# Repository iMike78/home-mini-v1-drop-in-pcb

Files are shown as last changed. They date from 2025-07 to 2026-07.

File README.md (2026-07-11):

# MiciMike drop-in PCB replacement for Google Home Mini (Gen 1)

[MiciMike Home Mini](https://github.com/iMike78/home-mini-v1-drop-in-pcb) is a drop-in PCB replacement for the original [Google Home Mini](https://en.wikipedia.org/wiki/Google_Nest_(smart_speakers)) with the Micro-USB power connector. It replaces the original electronics with open-source hardware based on an ESP32-S3 and an XMOS xCORE audio processor, and is intended to run ESPHome-based open voice assistant firmware.

The project follows the Home Assistant Voice Preview Edition architecture as closely as the Google Home Mini enclosure allows, while adapting the layout, connectors, controls, microphones, LEDs, and audio path to the original speaker shell.

## Current Status

- Schematic completed
- Component placement completed
- Routing completed
- Ground pour, shielding, and EMI strategy completed
- First prototype batch tested
- Validation batch received and under test
- ESPHome factory provisioning validated with BLE Improv and Home Assistant discovery

## Update: v0.9.5 Touch Controller Migration and Test Points

### Touch Controller Change

The ESP32-S3 built-in touch peripheral has been replaced with an external **MPR121 capacitive touch controller** on the I2C bus at address `0x5A`. This avoids an unresolved ESP-IDF / hardware issue (`IDFGH-16448`) where the touch sensor FSM could lock up and leave all channels stuck at their maximum raw value.

What changed:

- **Hardware:** MPR121 added on the clean `+3V3` rail. Touch pads connect through `ELEC0` to `ELEC2`; IRQ is on `GPIO2`. Unused electrodes are tied together to GND through a single 1 Mohm resistor.
- **Firmware:** the ESPHome `esp32_touch` component was removed and replaced with an `mpr121` hub plus three binary sensors for `volume_down`, `center_button`, and `volume_up`.
- **Freed pins:** ESP32-S3 `GPIO3` and `GPIO4` are no longer used for capacitive touch.

The center touch button is also used as the BLE Improv authorizer in the factory firmware, matching the Home Assistant Voice PE provisioning flow.

### New Solderable Test Points

The board exposes large, easy-to-solder test points for users who do not have the original Google Home Mini daughterboard and FPC connector, or who want to integrate the PCB into a custom enclosure.

- **+5V and GND power input pads:** allow direct power injection without using the original FPC connector.
- **Mute switch pad:** exposes the hardware mute input, which has an on-board pull-up. Pull this pad to GND to power the microphones; otherwise the board remains muted and the microphone path is disabled.

## ESPHome Firmware

The ESPHome configuration lives in [esphome/](./esphome/):

- [micimike-factory.yml](./esphome/micimike-factory.yml) is the manufacturing / first-install firmware. It mirrors the Home Assistant Voice PE factory flow: BLE Improv provisioning, center-button authorization, Home Assistant discovery, and the full voice firmware configuration included underneath.
- [micimike-voice.yml](./esphome/micimike-voice.yml) is the full voice assistant firmware configuration used by the factory build and by normal ESPHome installs.

Typical factory flashing:

```bash
esphome run esphome/micimike-factory.yml
```

After flashing, Home Assistant should discover the device via BLE Improv, ask for Wi-Fi credentials, request center-button authorization, and then add the ESPHome device. The fallback Wi-Fi AP is present, but no captive portal or web server is intentionally enabled.

## Crowdfunding

The crowdfunding campaign is live on Crowd Supply in its pre-order phase. You can subscribe there to show interest and receive email updates:

https://www.crowdsupply.com/micimike-rev-devices/micimike-home-mini-drop-in-pcb

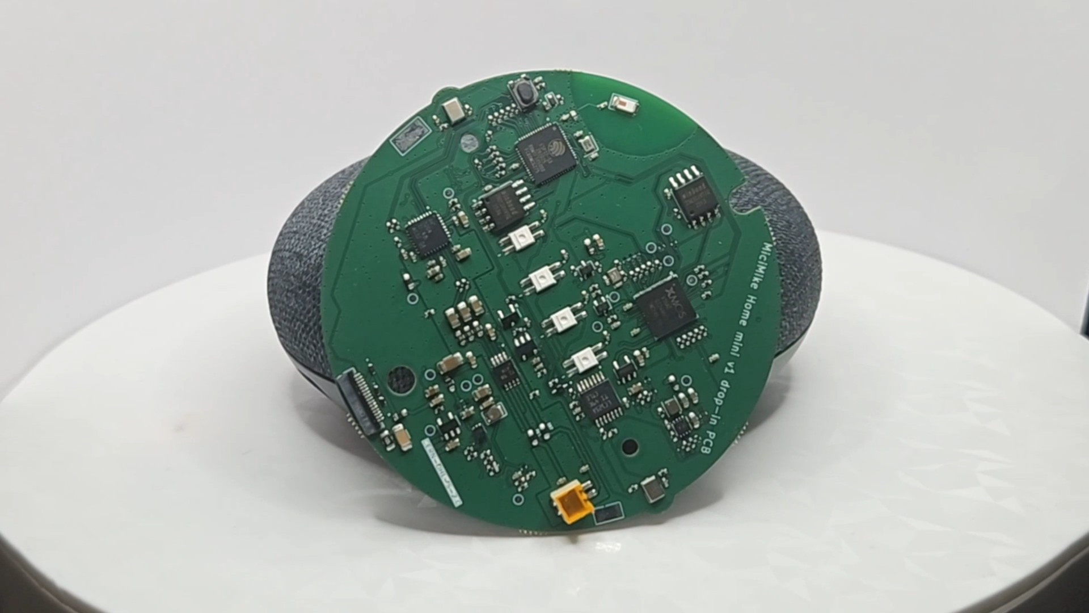
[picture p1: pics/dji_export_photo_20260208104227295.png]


If you are looking for a similar drop-in PCB replacement for the Google Nest Mini, see the sister project:

https://github.com/iMike78/nest-mini-drop-in-pcb

## Project Scope

This repository and its sister project are open-source hardware projects inspired in part by [Onju Voice](https://github.com/justLV/onju-voice), but designed around the open voice assistant hardware direction established by the Open Home Foundation and Home Assistant Voice Preview Edition.

The primary target audience is people who want to repurpose Google Home Mini and Google Nest Mini speakers into open-source Home Assistant voice assistant hardware and/or media player speaker output for [Music Assistant](https://www.music-assistant.io). The hardware may also be useful for other ESP32-based firmware projects.

The design integrates:

- ESP32-S3 for Wi-Fi, BLE, ESPHome, and onboard wake-word detection
- XMOS xCORE XU316 for advanced audio processing
- Local audio cleanup support for noise suppression, acoustic echo cancellation, interference cancellation, and automatic gain control

Functionally, the goal is to stay as compatible as practical with the [Home Assistant Voice Preview Edition](https://www.home-assistant.io/blog/2024/12/19/voice-preview-edition-the-era-of-open-voice/) reference design. The main differences come from the tight mechanical constraints of the Google Home Mini enclosure and original components.

This repository is not intended to become a separate upstream for new ESPHome or XMOS voice features. Feature development should generally happen upstream:

- https://github.com/esphome/home-assistant-voice-pe
- https://github.com/esphome/esphome
- https://github.com/esphome/voice-kit-xmos-firmware

## Collaboration and Contributions

If you would like to support the project, you can buy me a coffee via Ko-fi:

https://ko-fi.com/imike78

Contributions are especially welcome from people with board-level electrical design, KiCad layout, PCB routing, ground-pour strategy, EMI, and mixed-signal audio layout experience. Please open an issue, join an existing discussion, or start a new discussion in this repository.

Background discussion on the Home Assistant community forum:

https://community.home-assistant.io/t/any-news-on-alternative-to-onju-voice-pcb-repacement-design-for-google-nest-home-mini-speakers-with-added-xmos-chip-to-match-of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

## Tools Used

- KiCad 9
- SnapEDA / LCSC for footprint sourcing

## Known Hardware Specifications

- 4-layer PCB
- ESP32-S3R8 bare chip with 16MB flash
- XMOS XU316-1024-QF60B-C24 xCORE DSP audio processor with 4MB flash
- Dual I2S buses for simultaneous audio input and output
- AIC3204 DAC and TPA6211 power amplifier for speaker output
- 2x T3902 MEMS microphones with 68mm spacing
- 4x SK6812 RGB LEDs
- MPR121 capacitive touch controller

## References

### Home Assistant Voice Preview Edition

- https://www.home-assistant.io/blog/2024/12/19/voice-preview-edition-the-era-of-open-voice/
- https://voice-pe.home-assistant.io/resources/
- https://support.nabucasa.com/hc/en-us/categories/24451727188125-Home-Assistant-Voice-Preview-Edition
- https://github.com/esphome/home-assistant-voice-pe
- https://esphome.github.io/home-assistant-voice-pe/

### XMOS xCORE DSP

- https://www.xmos.com/download/XU316-1024-QF60B-xcore.ai-Datasheet(3).pdf
- https://www.xmos.com/software-tools/
- https://www.xmos.com/develop/xcore-voice
- https://www.xmos.com/usb-multichannel-audio/
- https://www.xmos.com/xcore-ai

### XMOS Firmware

- https://github.com/esphome/voice-kit-xmos-firmware
- https://github.com/esphome/xmos_fwk_rtos
- https://github.com/esphome/xmos_fwk_io

## License

This project is licensed under the [CERN Open Hardware License Version 2 - Strongly Reciprocal (CERN-OHL-S v2)](./LICENCE).

Any modified version of this hardware must also be distributed under the same license.

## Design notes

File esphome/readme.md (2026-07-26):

# MiciMike ESPHome Firmware

This directory contains the ESPHome firmware configuration for MiciMike.

## Files

```text
esphome/
|-- micimike-factory.yml  # Factory / first-install firmware
|-- micimike-voice.yml    # Full voice assistant firmware
```

## Factory Firmware

`micimike-factory.yml` follows the Home Assistant Voice Preview Edition factory pattern. It is not a tiny bootstrap-only image; it includes the full MiciMike voice assistant configuration and adds the first-install provisioning layer on top.

The factory overlay provides:

- BLE Improv provisioning
- Serial Improv provisioning
- Home Assistant discovery
- Center-button authorization for BLE Improv
- BLE disable after Wi-Fi connection, after a short delay so Improv can report success
- HTTP update entity backed by the GitHub release manifest
- Optional beta firmware update source switch

The fallback Wi-Fi AP is present, but `captive_portal:` and `web_server:` are intentionally not enabled. ESPHome may warn about this during validation; that is expected for this provisioning model.

## BLE Improv Flow

1. Flash the factory firmware over USB.
2. Home Assistant discovers the device via BLE Improv.
3. Home Assistant asks for Wi-Fi credentials.
4. Home Assistant asks for center-button authorization.
5. The device connects to Wi-Fi and is added as an ESPHome device.

The center button is implemented through the MPR121 capacitive touch controller on channel 1.

## Home Assistant Takeover

Factory firmware advertises the full `micimike-voice.yml` configuration through `dashboard_import` and enables full configuration import. After Home Assistant takes control, the generated ESPHome configuration should be the complete voice firmware config, not a short package wrapper pointing back to `micimike-factory.yml`.

The imported configuration must not add a station Wi-Fi `ssid` or `password`. Wi-Fi credentials entered through BLE Improv are stored on the device and should be preserved across OTA updates. Adding `wifi_ssid` / `wifi_password` secrets to the adopted config will override the Improv-provisioned network on the next ESPHome build.

If a device was adopted before this behavior was fixed, delete or manually repair the old short wrapper config in ESPHome before updating it again.

## Flashing

From the repository root:

```bash
esphome run esphome/micimike-factory.yml
```

To flash a known serial port:

```bash
esphome run esphome/micimike-factory.yml --device COM8
```

## Release Manifest

GitHub releases should provide `manifest.json`, `manifest-beta.json`, and the firmware binary referenced by the manifest.

Example:

```json
{
  "name": "MiciMike Voice Assistant",
  "version": "v0.9.8.2",
  "builds": [
    {
      "chipFamily": "ESP32-S3",
      "improv": false,
      "parts": [
        {
          "path": "micimike-voice.bin",
          "offset": 0
        }
      ]
    }
  ]
}
```

Expected release assets:

```text
manifest.json
manifest-beta.json
micimike-voice.bin
```

## Notes

- The factory firmware mirrors the Home Assistant Voice PE provisioning behavior as closely as possible.
- The factory firmware already contains the full voice assistant configuration through `micimike-voice.yml`.
- Home Assistant takeover should import the full `micimike-voice.yml` config and preserve BLE Improv Wi-Fi credentials.
- The HTTP update entity can check the GitHub release manifest, but installing an update still depends on the ESPHome/Home Assistant update flow.
- Future firmware updates are not forced automatically; users can update through Home Assistant or ESPHome when a release is available.

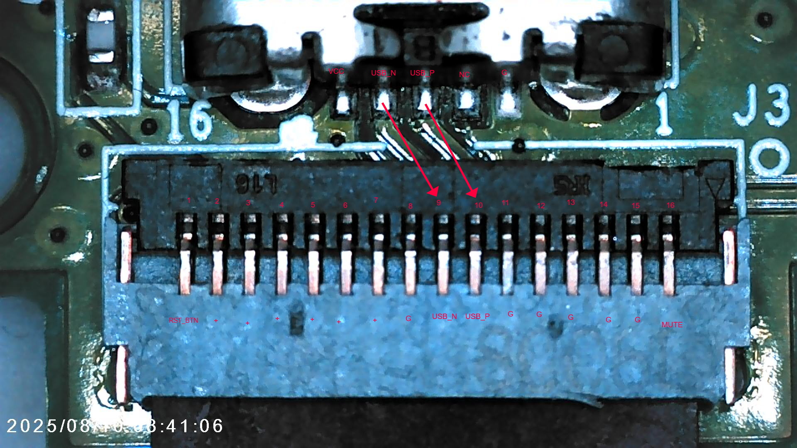
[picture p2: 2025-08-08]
pics/FPC_pinout.jpg

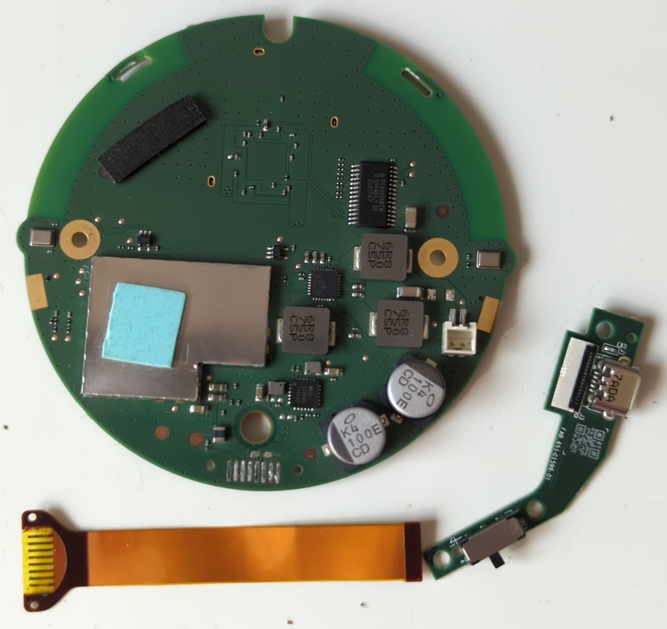
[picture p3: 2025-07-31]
pics/original_PCB.jpg

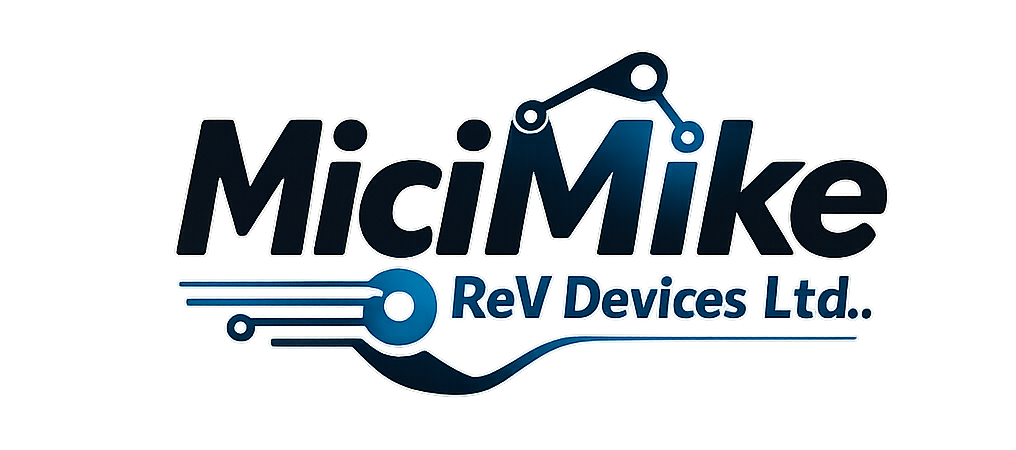
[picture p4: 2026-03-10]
pics/MiciMike.png

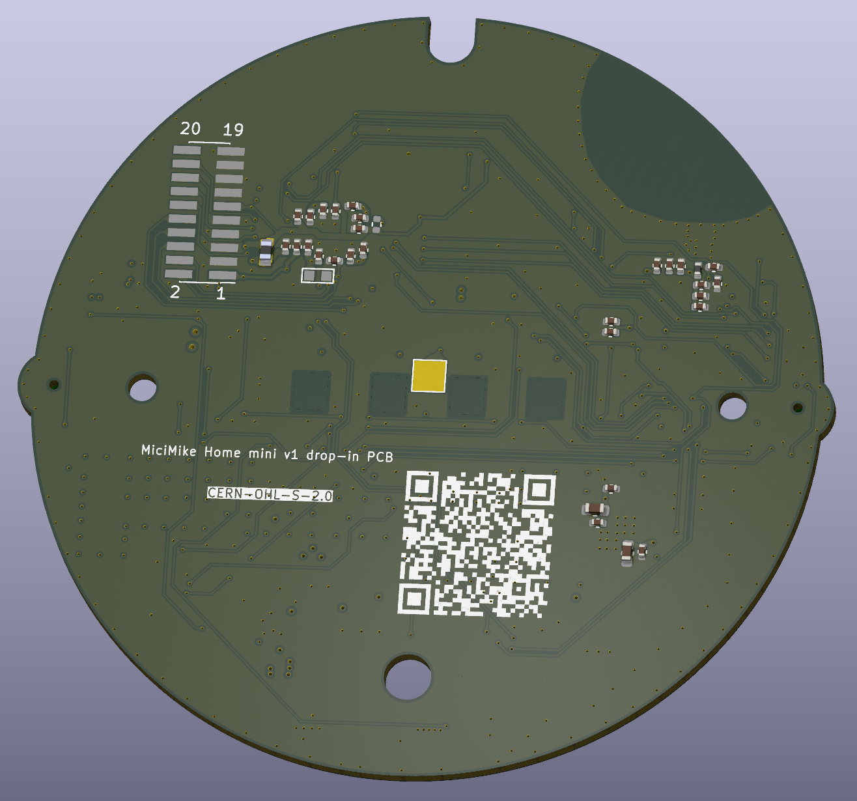
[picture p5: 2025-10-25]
pics/3D_bottom.png

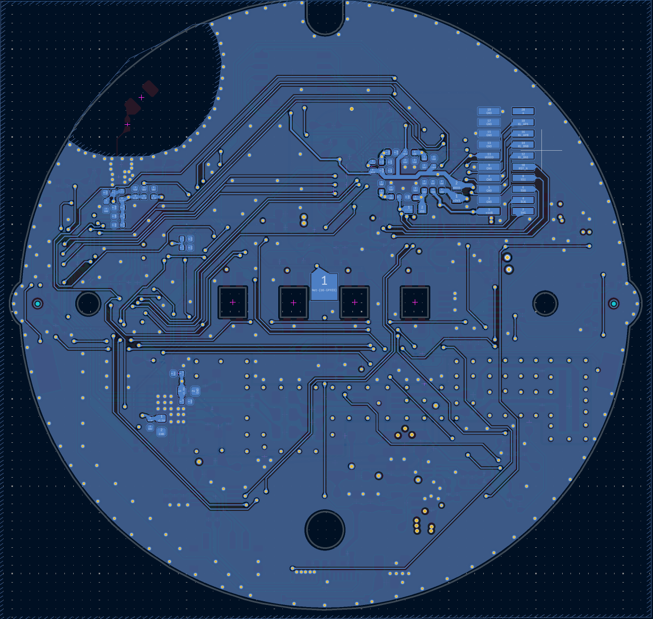
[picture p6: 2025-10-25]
pics/B_Cu.png

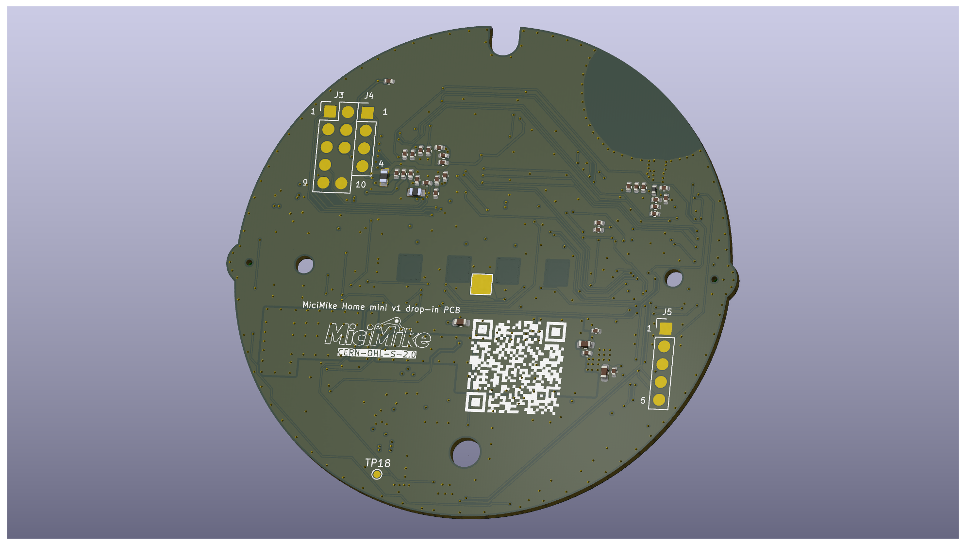
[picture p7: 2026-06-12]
pics/home-mini-DiP-Gen1-back.png

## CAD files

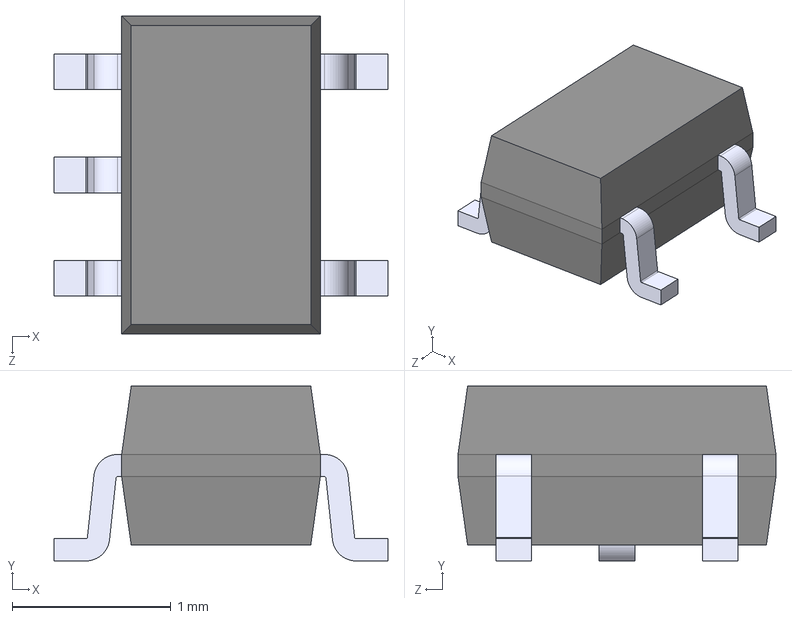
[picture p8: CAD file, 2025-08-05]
parts/MIC5365-1.8YC5-TR.step
2.10 x 1.10 x 2.00 mm

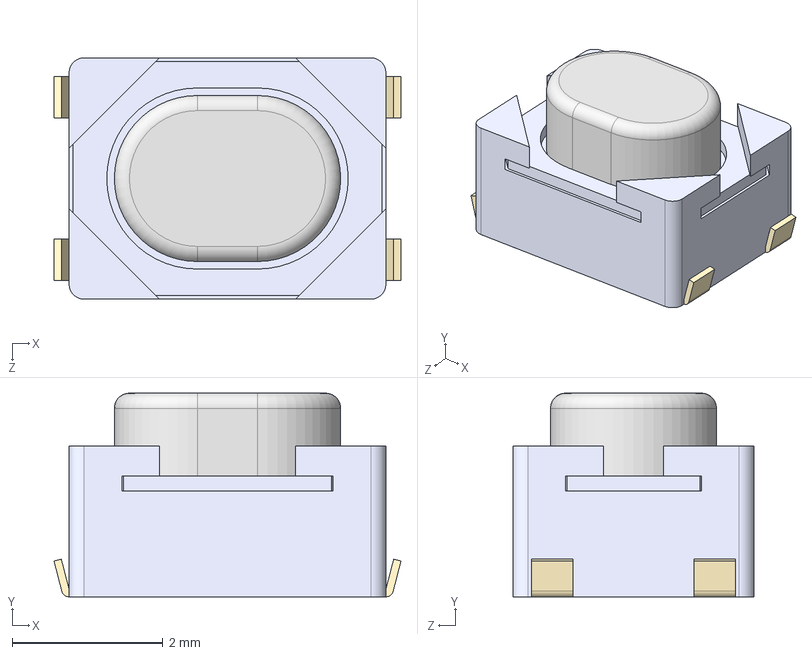
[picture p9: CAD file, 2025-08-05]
parts/PTS810SJS250SMTRLFS--3DModel-STEP-56544.STEP
4.60 x 2.70 x 3.20 mm

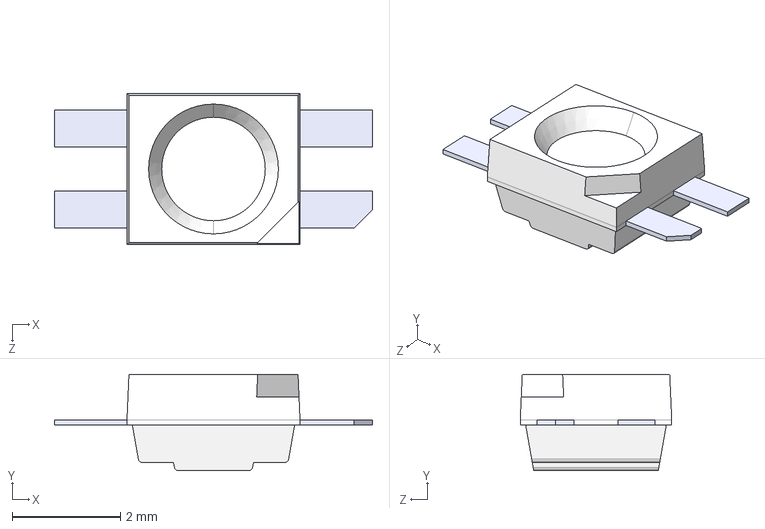
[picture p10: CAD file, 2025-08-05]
parts/SK6812-E.step
5.88 x 1.78 x 2.80 mm

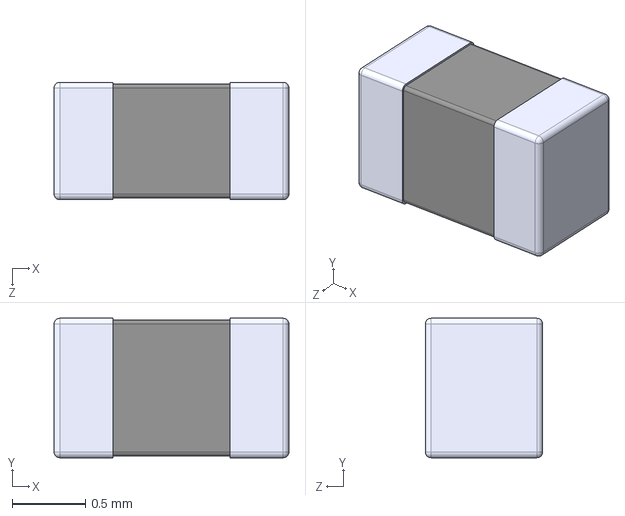
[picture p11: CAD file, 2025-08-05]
parts/BLM18PG121SN1D.step
1.60 x 0.95 x 0.8 mm

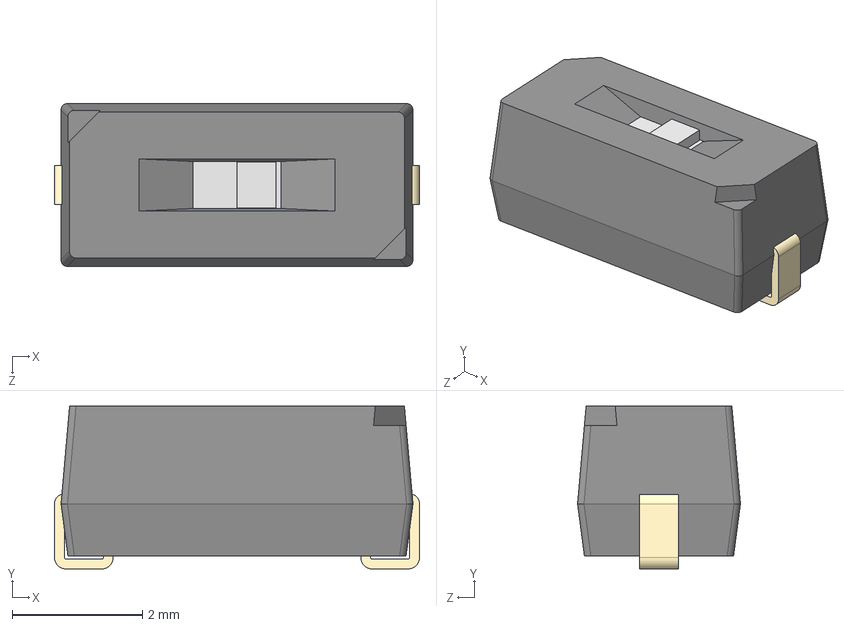
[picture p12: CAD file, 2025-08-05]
parts/CHS-01TA.step
5.60 x 2.50 x 2.50 mm
CHS-01 body
pin^CHS-01xx
switch^CHS-01xx

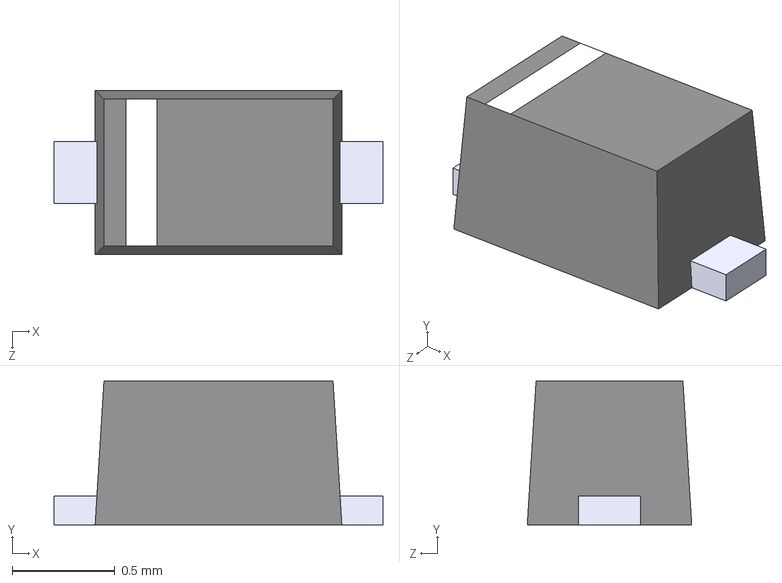
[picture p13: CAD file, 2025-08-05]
parts/RB521S30T1G.step
1.60 x 0.7 x 0.8 mm

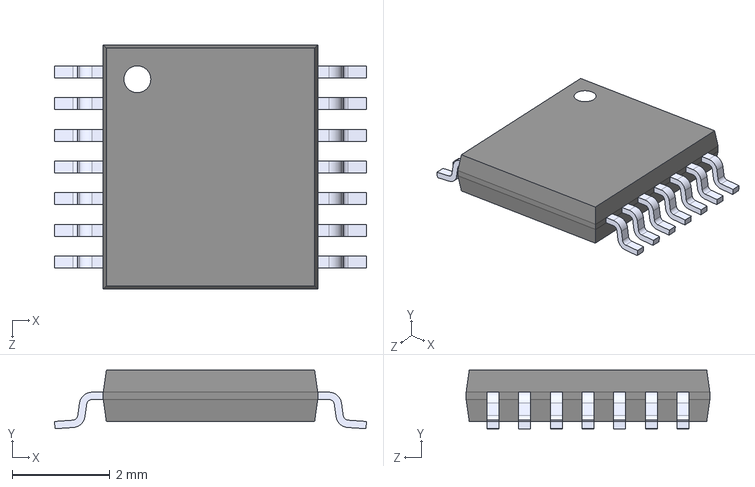
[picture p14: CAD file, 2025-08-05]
parts/SN74LVC125APWR.step
6.40 x 1.20 x 5.00 mm

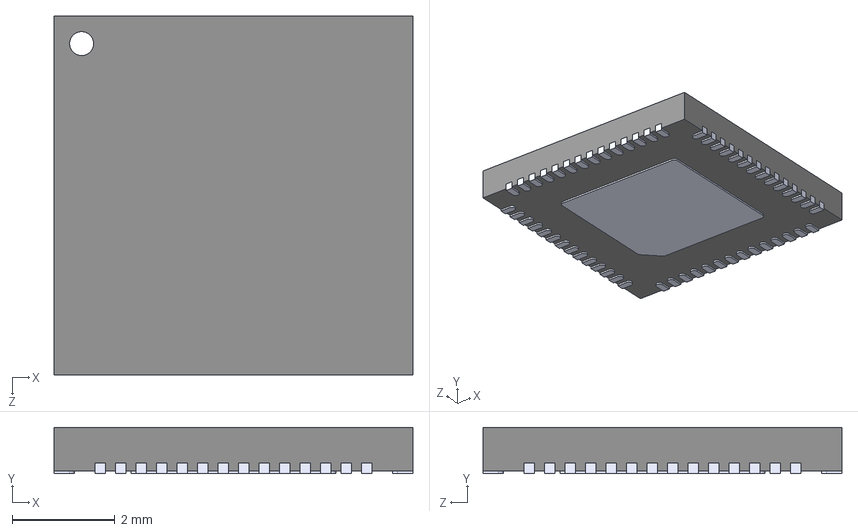
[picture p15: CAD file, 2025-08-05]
parts/ESP32-S3R8.step
7.00 x 0.9 x 7.00 mm

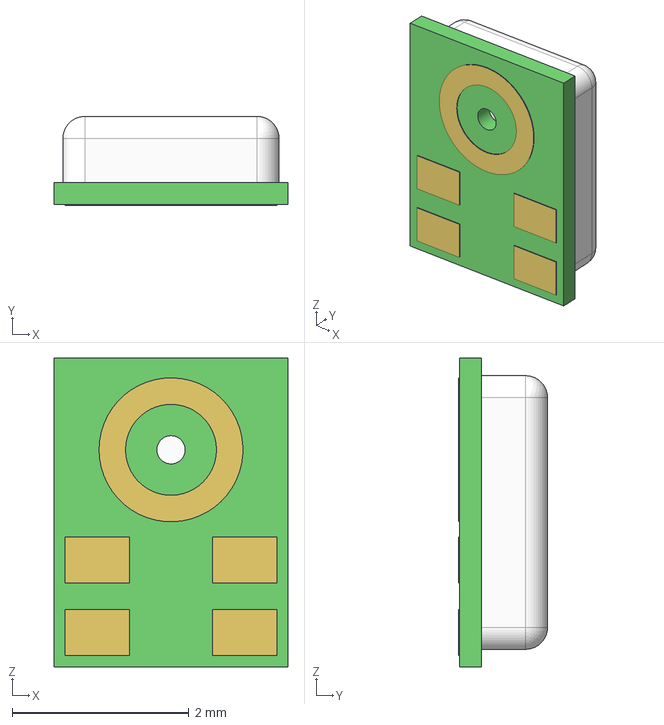
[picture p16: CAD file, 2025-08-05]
parts/DMM-3526-B-R.step
2.65 x 1.01 x 3.50 mm

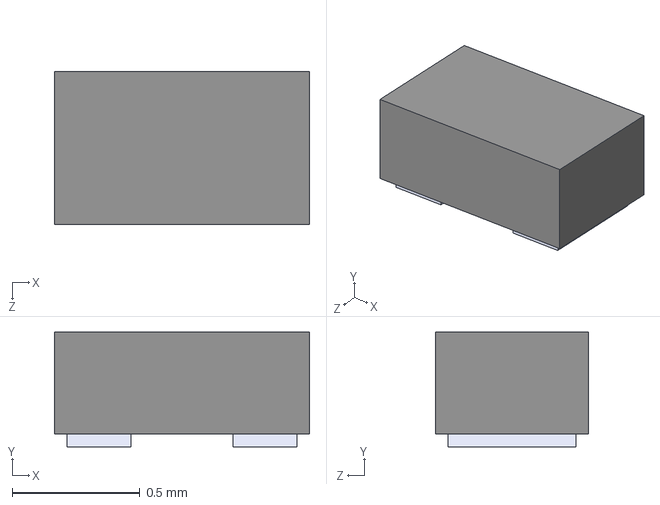
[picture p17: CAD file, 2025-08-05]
parts/TPD1E10B06DPYR.step
1.00 x 0.45 x 0.6 mm

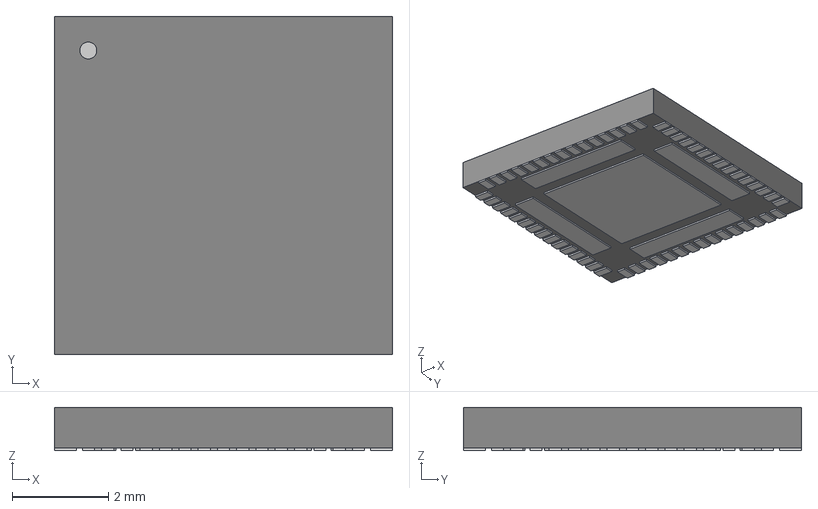
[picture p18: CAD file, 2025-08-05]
parts/QFN_F60B-C24_XMO.step
7.01 x 7.01 x 0.892 mm

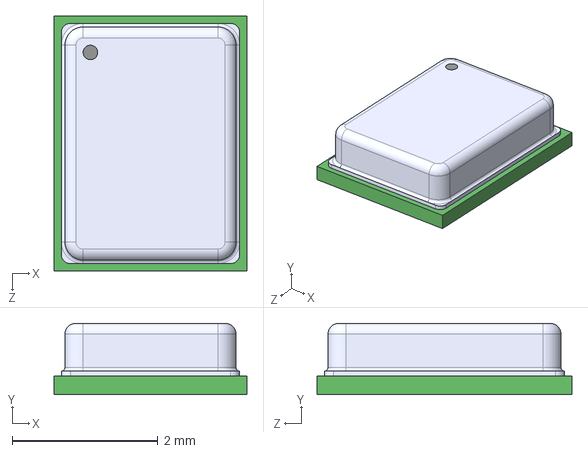
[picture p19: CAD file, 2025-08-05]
parts/T3902.step
2.65 x 0.98 x 3.50 mm

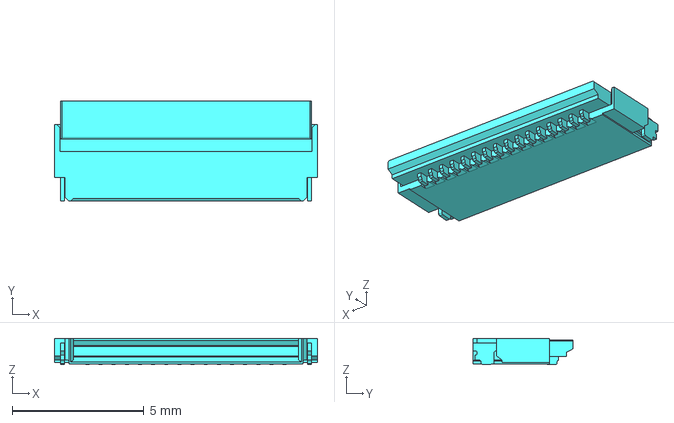
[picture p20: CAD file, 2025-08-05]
parts/FH34SRJ-16S-0.5SH-99---3DModel-STEP-1.STEP
10.0 x 3.80 x 1.00 mm

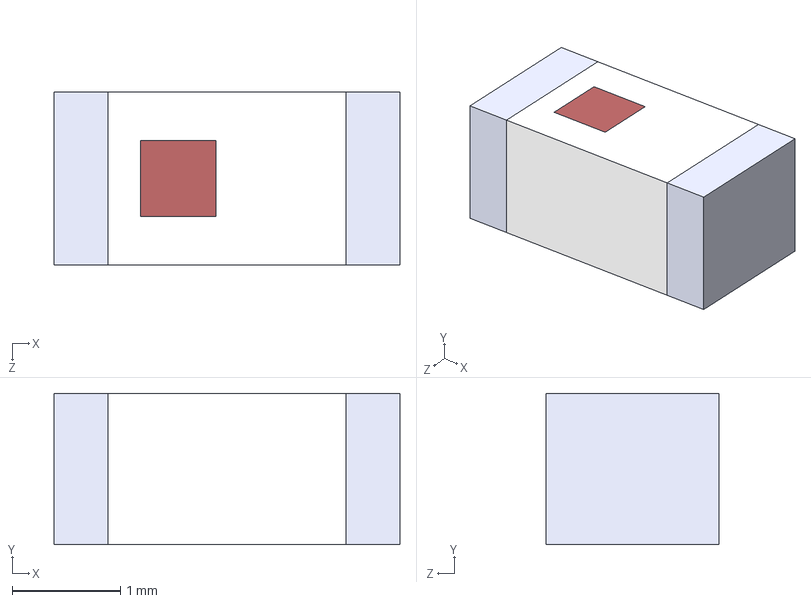
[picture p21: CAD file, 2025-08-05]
parts/2450AT18A100E.step
3.20 x 1.40 x 1.60 mm

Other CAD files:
parts/1775443-2.stp
parts/MAX98357AETE_T.step
parts/TLV73333PDBVR.step
parts/TPS563201DDCT.step

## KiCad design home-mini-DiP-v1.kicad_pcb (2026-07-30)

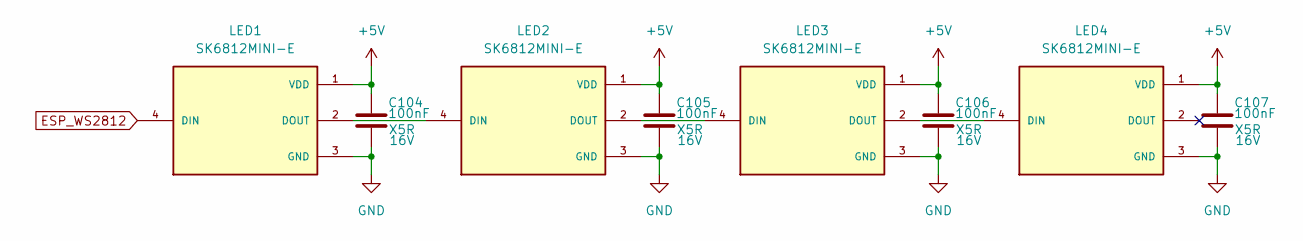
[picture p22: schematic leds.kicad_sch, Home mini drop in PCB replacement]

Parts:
C104, C105, C106, C107: 100nF; C_0402_1005Metric; Voltage 16V; Manufacturer Part CL05B104KO5NNNC; LCSC Part # C1525
LED1, LED2, LED3, LED4: SK6812MINI-E; Manufacturer Part SK6812MINI-E; LCSC Part # C5149201

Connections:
+5V: C104.1, C105.1, C106.1, C107.1, LED1.1 (VDD), LED2.1 (VDD), LED3.1 (VDD), LED4.1 (VDD); also elsewhere on the board
ESP_WS2812: LED1.4 (DIN); also elsewhere on the board
GND: C104.2, C105.2, C106.2, C107.2, LED1.3 (GND), LED2.3 (GND), LED3.3 (GND), LED4.3 (GND); also elsewhere on the board
unnamed: LED1.2 (DOUT), LED2.4 (DIN)
unnamed: LED2.2 (DOUT), LED3.4 (DIN)
unnamed: LED3.2 (DOUT), LED4.4 (DIN)

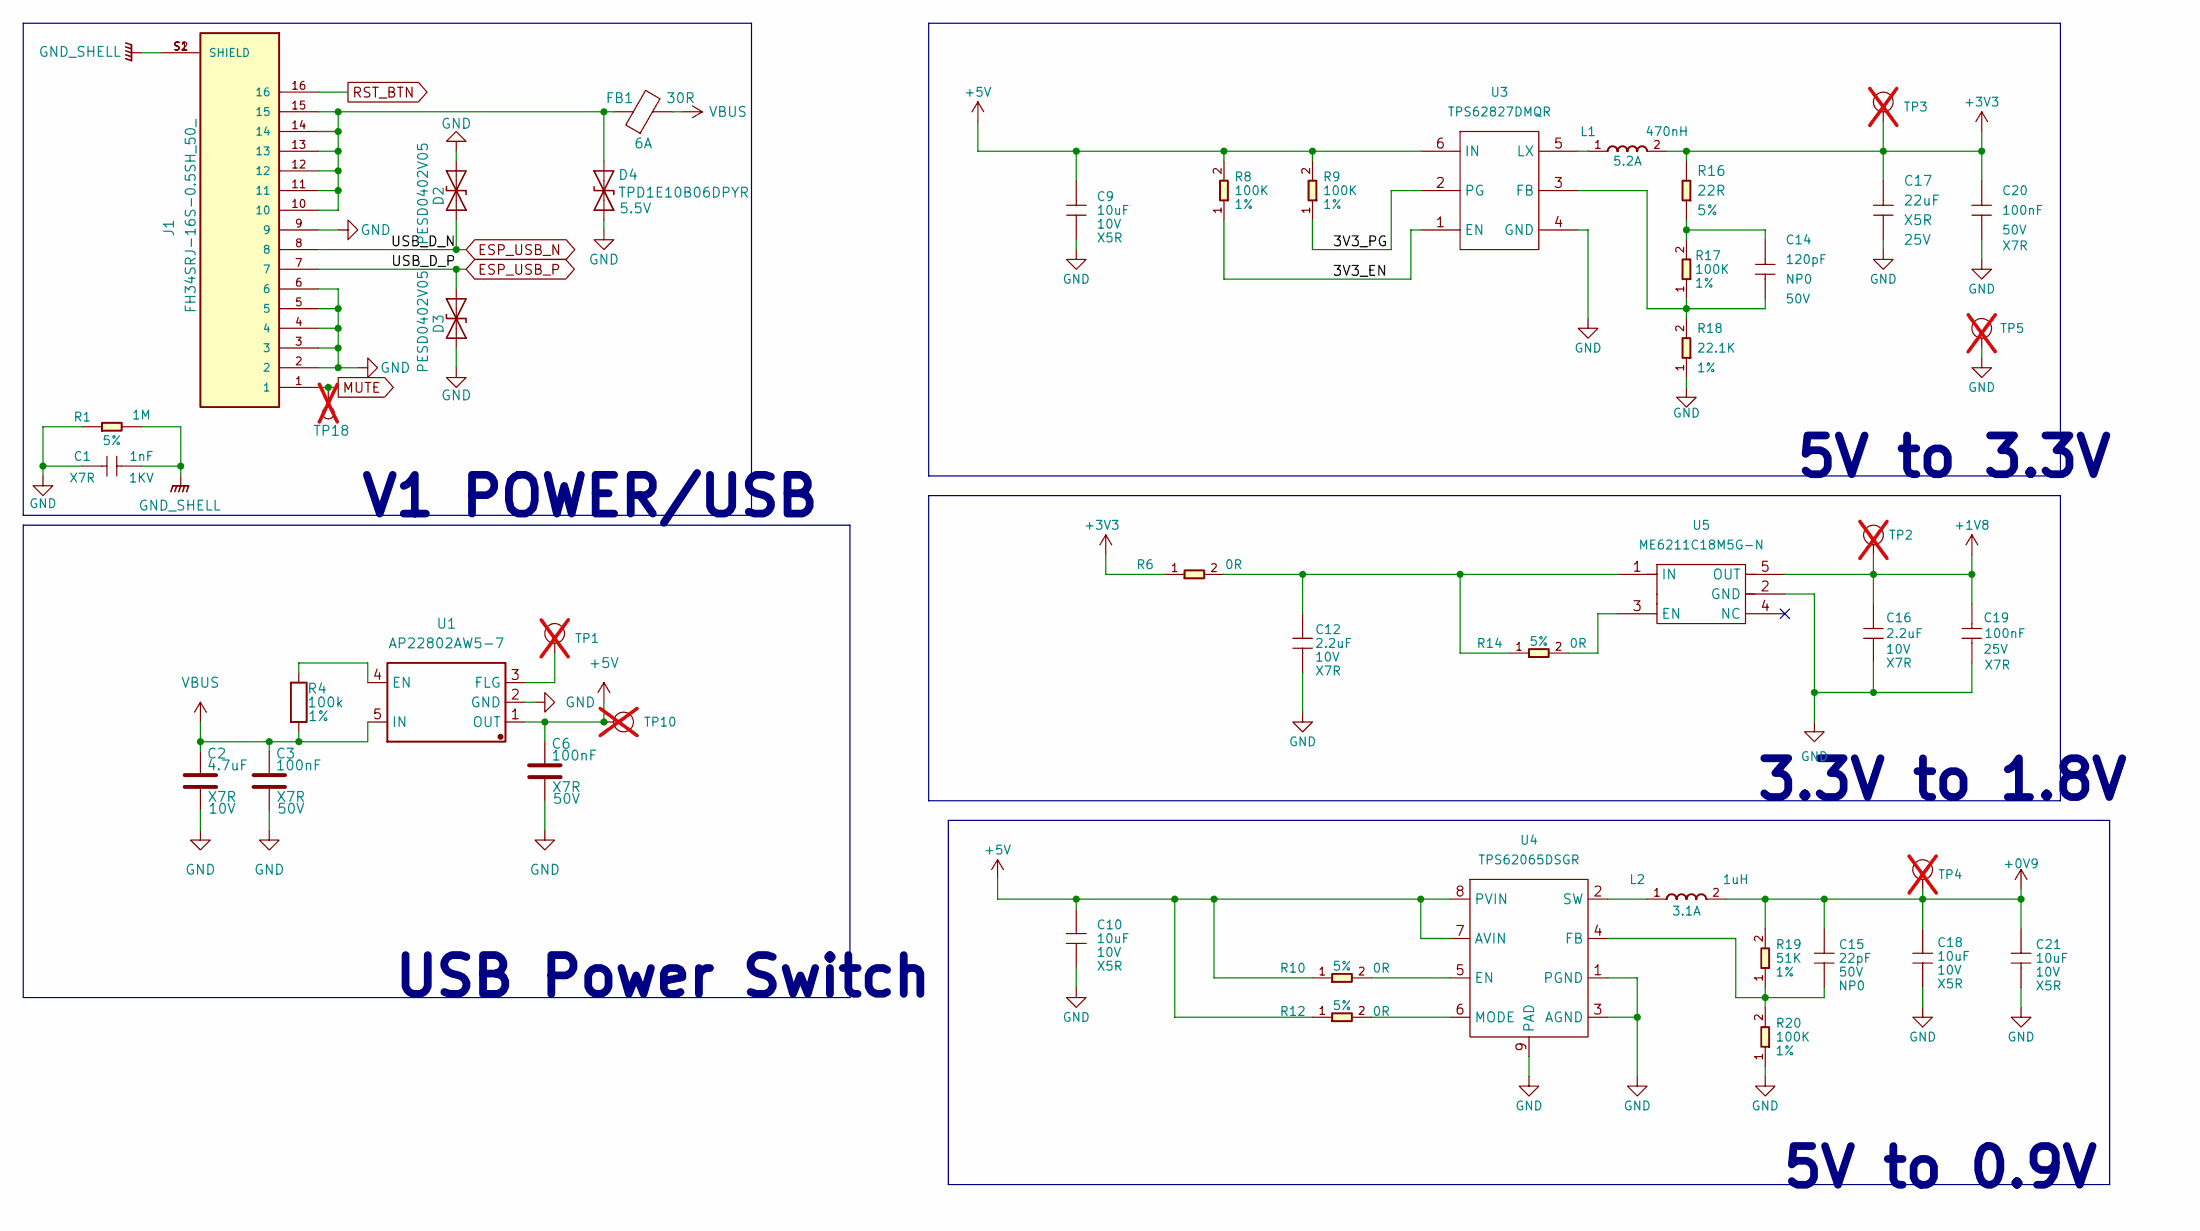
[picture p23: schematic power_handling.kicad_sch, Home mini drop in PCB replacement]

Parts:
C1: 1nF; C_1206_3216Metric; Voltage Rating 1KV; Voltage 2kV; MPN 1206B102K202NT; LCSC Part # C9196
C2: 4.7uF; C_0603_1608Metric; Voltage 10V; Manufacturer Part GRM188Z71A475KE15D; LCSC Part # C913474
C3, C6: 100nF; C_0603_1608Metric; Voltage 50V; Manufacturer Part CC0603KRX7R9BB104; LCSC Part # C14663
C9, C10, C18, C21: 10uF; C_0603_1608Metric; Voltage Rating 10V; Voltage 10V; MPN CL10A106KP8NNNC; LCSC Part # C19702
C12, C16: 2.2uF; C_0603_1608Metric; Voltage Rating 10V; Voltage 16V; MPN 0603B225K160NT; LCSC Part # C43922
C14: 120pF; C_0402_1005Metric; Voltage Rating 50V; Voltage 50V; MPN 0402CG121J500NT; LCSC Part # C40059
C15: 22pF; C_0402_1005Metric; Voltage Rating 50V; Voltage 50V; MPN 0402CG220J500NT; LCSC Part # C1555
C17: 22uF; C_0805_2012Metric; Voltage Rating 25V; Voltage 25V; MPN CL21A226MAQNNNE; LCSC Part # C45783
C19: 100nF; C_0402_1005Metric; Voltage Rating 25V; Voltage 16V; MPN CL05B104KO5NNNC; LCSC Part # C1525
C20: 100nF; C_0603_1608Metric; Voltage Rating 50V; Voltage 50V; MPN CC0603KRX7R9BB104; LCSC Part # C14663
D2, D3: PESD0402V05; D_0402_1005Metric; Manufacturer Part PESD0402V05; LCSC Part # C19626254
D4: TPD1E10B06DPYR; TPD1E05U06DPYR; Voltage 5.5V; Manufacturer Part TPD1E10B06DPYR; LCSC Part # C48260
FB1: 30R; BLM18PG300SN1D; Manufacturer Part BLM18PG300SN1D; LCSC Part # C17305
J1: FH34SRJ-16S-0.5SH_50_; HRS_FH34SRJ-16S-0.5SH_50_; Manufacturer Part FH34SRJ-16S-0.5SH(50); LCSC Part # C324725
L1: 470nH; L0806; Rating 5.2A; MPN WPN201610MR47MT; LCSC Part # C97014
L2: 1uH; L_Murata_DFE201610P; Rating 3.1A; MPN WPN201610U1R0MTY01; LCSC Part # C395545
R1: 1M; R_0805_2012Metric; Power Rating 5%; MPN RC0805JR-071ML; LCSC Part # C107699
R4: 100k; R_0402_1005Metric; Tolerance 1%; Manufacturer Part 0402WGJ0104TCE; LCSC Part # C25530
R6, R10, R12, R14: 0R; R_0402_1005Metric; Tolerance 5%; MPN 0402WGF0000TCE; LCSC Part # C17168
R8, R9, R17: 100K; R_0402_1005Metric; Power Rating 1%; MPN 0402WGJ0104TCE; LCSC Part # C25530
R16: 22R; R_0402_1005Metric; Power Rating 5%; MPN 0402WGF220JTCE; LCSC Part # C25092
R18: 22.1K; R_0402_1005Metric; Power Rating 1%; MPN 0402WGF2212TCE; LCSC Part # C43473
R19: 51K; R_0402_1005Metric; Tolerance 1%; MPN 0402WGF5102TCE; LCSC Part # C25794
R20: 100K; R_0402_1005Metric; Tolerance 1%; MPN 0402WGJ0104TCE; LCSC Part # C25530
TP1, TP2, TP3, TP4: TEST-POINT; TestPoint_Pad_D1.0mm; not fitted
TP5, TP10: TEST-POINT; TestPoint_Pad_D3.0mm; not fitted
TP18: MUTE; TestPoint_Pad_D1.0mm; not fitted
U1: AP22802AW5-7; SOT-23-5; Manufacturer Part AP22802AW5-7; LCSC Part # C211404
U3: TPS62827DMQR; DFN6-0.5-1.5X1.5X0.65MM; MPN TPS62827DMQR; LCSC Part # C2071448
U4: TPS62065DSGR; MPN TPS62065DSGR; LCSC Part # C398352
U5: ME6211C18M5G-N; SOT-23-5; MPN ME6211C18M5G-N; LCSC Part # C236671

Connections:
+0V9: C15.1, C18.1, C21.1, L2.2, R19.2, TP4.1 (T); also elsewhere on the board
+1V8: C16.1, C19.1, TP2.1 (T), U5.5 (OUT); also elsewhere on the board
+3V3: C17.1, C20.1, L1.2, R6.1, R16.2, TP3.1 (T); also elsewhere on the board
+5V: C6.1, C9.1, C10.1, R8.2, R9.2, R10.1, R12.1, TP10.1 (T), U1.1 (OUT), U3.6 (IN), U4.7 (AVIN), U4.8 (PVIN); also elsewhere on the board
/Power/3V3_EN: R8.1, U3.1 (EN)
/Power/3V3_PG: R9.1, U3.2 (PG)
ESP_USB_N: D2.2 (A2), J1.8; also elsewhere on the board
ESP_USB_P: D3.1 (A1), J1.7; also elsewhere on the board
GND: C1.1, C2.2, C3.2, C6.2, C9.2, C10.2, C12.2, C16.2, C17.2, C18.2, C19.2, C20.2, C21.2, D2.1 (A1), D3.2 (A2), D4.1 (A1), J1.2, J1.3, J1.4, J1.5, J1.6, J1.9, R1.1, R18.1, R20.1, TP5.1 (T), U1.2 (GND), U3.4 (GND), U4.1 (PGND), U4.3 (AGND), U4.9 (PAD), U5.2 (GND); also elsewhere on the board
GND_SHELL: C1.2, J1.S1 (SHIELD), J1.S2 (SHIELD), R1.2
MUTE: J1.1, TP18.1; also elsewhere on the board
unnamed: C14.1, R16.1, R17.2
unnamed: D4.2 (A2), FB1.1, J1.10, J1.11, J1.12, J1.13, J1.14, J1.15
unnamed: TP1.1 (T), U1.3 (FLG)
unnamed: R4.1, U1.4 (EN)
unnamed: C14.2, R17.1, R18.2, U3.3 (FB)
unnamed: L1.1, U3.5 (LX)
unnamed: R10.2, U4.5 (EN)
unnamed: C15.2, R19.1, R20.2, U4.4 (FB)
unnamed: R12.2, U4.6 (MODE)
unnamed: L2.1, U4.2 (SW)
unnamed: R14.2, U5.3 (EN)
unnamed: C12.1, R6.2, R14.1, U5.1 (IN)
RST_BTN: J1.16; also elsewhere on the board
VBUS: C2.1, C3.1, FB1.2, R4.2, U1.5 (IN); also elsewhere on the board

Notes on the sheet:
V1 POWER/USB
USB Power Switch
3.3V to 1.8V
5V to 3.3V
5V to 0.9V

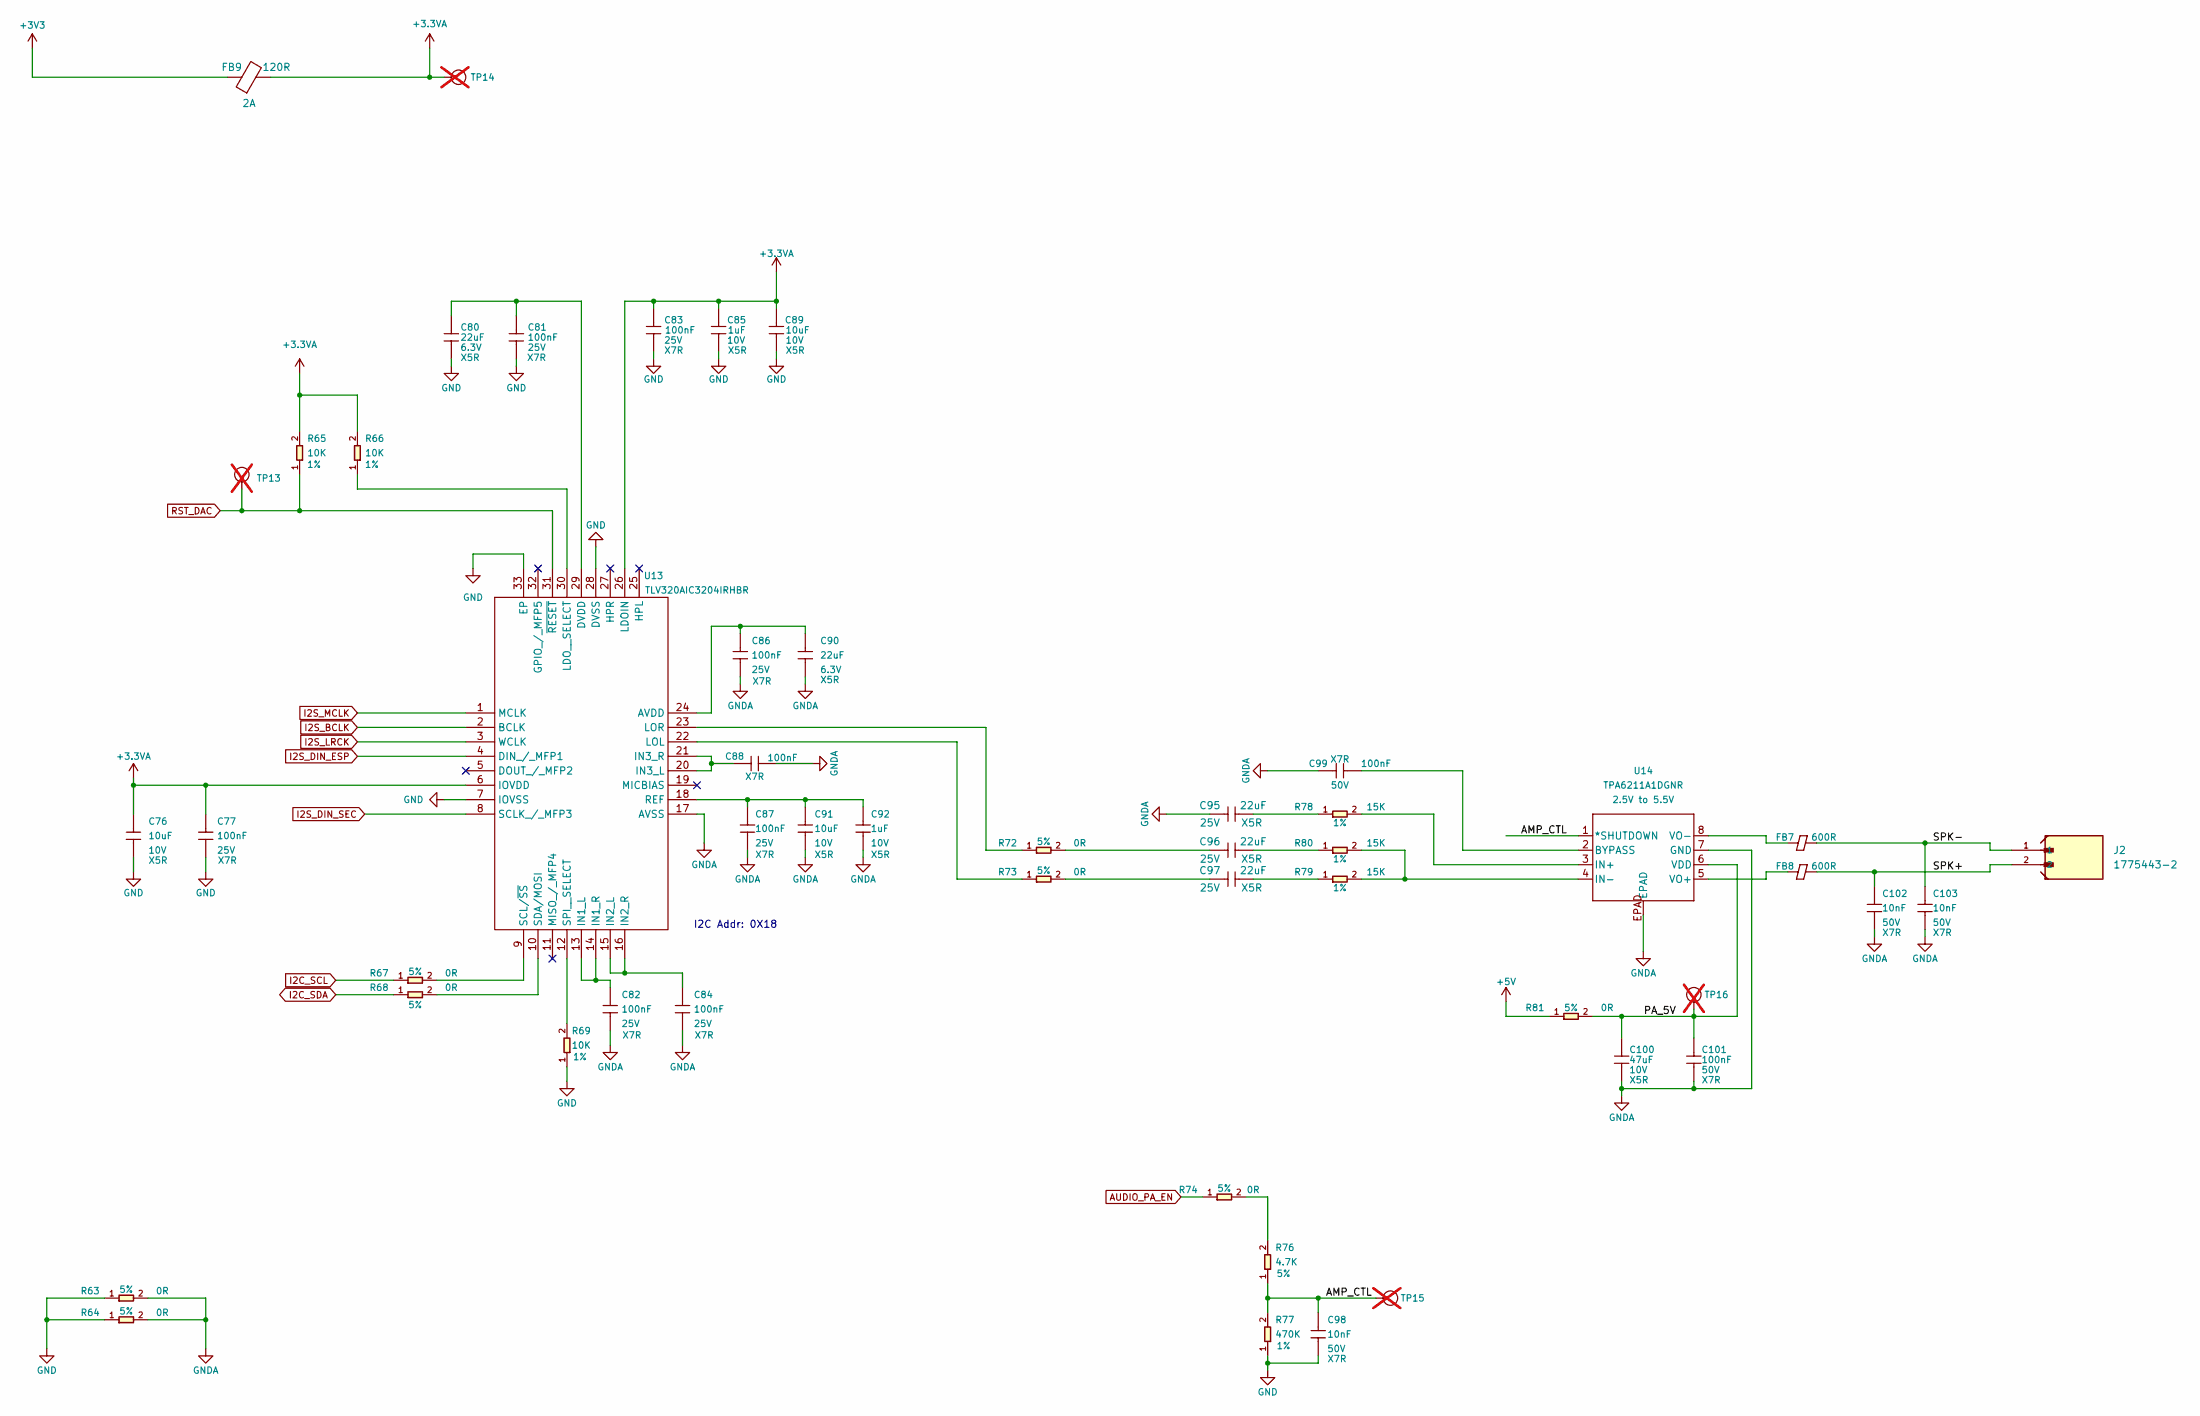
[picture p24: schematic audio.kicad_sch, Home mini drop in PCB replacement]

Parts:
C76, C89, C91: 10uF; C_0603_1608Metric; Voltage Rating 10V; Voltage 10V; MPN CL10A106KP8NNNC; LCSC Part # C19702
C77, C81, C82, C83, C84, C86, C87, C88: 100nF; C_0402_1005Metric; Voltage Rating 25V; Voltage 16V; MPN CL05B104KO5NNNC; LCSC Part # C1525
C80, C90: 22uF; C_0603_1608Metric; Voltage Rating 6.3V; Voltage 6.3V; MPN CL10A226MQ8NRNC; LCSC Part # C59461
C85, C92: 1uF; C_0402_1005Metric; Voltage Rating 10V; MPN CL05A105KA5NQNC; LCSC Part # C52923
C95, C96, C97: 22uF; C_0805_2012Metric; Voltage Rating 25V; Voltage 25V; MPN CL21A226MAQNNNE; LCSC Part # C45783
C98, C102, C103: 10nF; C_0402_1005Metric; Voltage Rating 50V; Voltage 50V; MPN CL05B103KB5NNNC; LCSC Part # C15195
C99, C101: 100nF; C_0603_1608Metric; Voltage Rating 50V; Voltage 50V; MPN CC0603KRX7R9BB104; LCSC Part # C14663
C100: 47uF; C_1206_3216Metric; Voltage Rating 10V; Voltage 10V; MPN CL31A476MPHNNNE; LCSC Part # C96123
FB7, FB8: 600R; BLM18PG121SN1D; Rating 500mA; MPN BLM18KG601SN1D; LCSC Part # C85833
FB9: 120R; BLM18PG121SN1D; Manufacturer Part BLM18PG121SN1D; LCSC Part # C14709
J2: 1775443-2; Manufacturer Part 1775443-2; LCSC Part # C5162845
R63, R64, R67, R68, R72, R73, R74: 0R; R_0402_1005Metric; Tolerance 5%; MPN 0402WGF0000TCE; LCSC Part # C17168
R65, R66, R69: 10K; R_0402_1005Metric; Tolerance 1%; MPN 0402WGF1002TCE; LCSC Part # C25744
R76: 4.7K; R_0402_1005Metric; Tolerance 5%; MPN 0402WGF4701TCE; LCSC Part # C25900
R77: 470K; R_0402_1005Metric; Tolerance 1%; Manufacturer Part 0402WGF4703TCE; LCSC Part # C25790
R78, R79, R80: 15K; R_0603_1608Metric; Tolerance 1%; Manufacturer Part 0603WAF1502T5E; LCSC Part # C22809
R81: 0R; R_0603_1608Metric; Tolerance 5%; Manufacturer Part 0603WAF0000T5E; LCSC Part # C21189
TP13, TP15: TEST-POINT; TestPoint_Pad_D1.0mm; not fitted
TP14, TP16: Test Point; TestPoint_Pad_D1.0mm; Part Type Test Point; not fitted
U13: TLV320AIC3204IRHBR; MPN TLV320AIC3204IRHBR; Mouser Part Number 595-V320AIC3204IRHBR
U14: TPA6211A1DGNR; Rating 2.5V to 5.5V; MPN TPA6211A1DGNR; LCSC Part # C7718

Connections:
+3.3VA: C76.1, C77.1, C83.1, C85.1, C89.1, FB9.2, R65.2, R66.2, TP14.1 (T), U13.6 (IOVDD), U13.26 (LDOIN)
+3V3: FB9.1; also elsewhere on the board
+5V: R81.1; also elsewhere on the board
/AUDIO/AMP_CTL: C98.1, R76.1, R77.2, TP15.1 (T), U14.1 (*SHUTDOWN)
/AUDIO/PA_5V: C100.1, C101.1, R81.2, TP16.1 (T), U14.6 (VDD)
/AUDIO/SPK+: C102.1, FB8.2, J2.2
/AUDIO/SPK-: C103.1, FB7.2, J2.1
AUDIO_PA_EN: R74.1; also elsewhere on the board
GND: C76.2, C77.2, C80.2, C81.2, C83.2, C85.2, C89.2, C98.2, R63.1, R64.1, R69.1, R77.1, U13.7 (IOVSS), U13.28 (DVSS), U13.33 (EP); also elsewhere on the board
GNDA: C82.2, C84.2, C86.2, C87.2, C88.2, C90.2, C91.2, C92.2, C95.1, C99.1, C100.2, C101.2, C102.2, C103.2, R63.2, R64.2, U13.17 (AVSS), U14.7 (GND), U14.EPAD
I2C_SCL: R67.1; also elsewhere on the board
I2C_SDA: R68.1; also elsewhere on the board
I2S_BCLK: U13.2 (BCLK); also elsewhere on the board
I2S_DIN_ESP: U13.4 (DIN_/_MFP1); also elsewhere on the board
I2S_DIN_SEC: U13.8 (SCLK_/_MFP3); also elsewhere on the board
I2S_LRCK: U13.3 (WCLK); also elsewhere on the board
I2S_MCLK: U13.1 (MCLK); also elsewhere on the board
unnamed: C95.2, R78.1
unnamed: C96.1, R72.2
unnamed: C96.2, R80.1
unnamed: C97.1, R73.2
unnamed: C97.2, R79.1
unnamed: R74.2, R76.2
unnamed: C86.1, C90.1, U13.24 (AVDD)
unnamed: C80.1, C81.1, U13.29 (DVDD)
unnamed: C82.1, U13.13 (IN1_L), U13.14 (IN1_R)
unnamed: C84.1, U13.15 (IN2_L), U13.16 (IN2_R)
unnamed: C88.1, U13.20 (IN3_L), U13.21 (IN3_R)
unnamed: R66.1, U13.30 (LDO__SELECT)
unnamed: R73.1, U13.22 (LOL)
unnamed: R72.1, U13.23 (LOR)
unnamed: C87.1, C91.1, C92.1, U13.18 (REF)
unnamed: R67.2, U13.9 (SCL/~SS)
unnamed: R68.2, U13.10 (SDA/MOSI)
unnamed: R69.2, U13.12 (SPI__SELECT)
unnamed: C99.2, U14.2 (BYPASS)
unnamed: R78.2, U14.3 (IN+)
unnamed: R79.2, R80.2, U14.4 (IN-)
unnamed: FB8.1, U14.5 (VO+)
unnamed: FB7.1, U14.8 (VO-)
RST_DAC: R65.1, TP13.1 (T), U13.31 (~RESET); also elsewhere on the board

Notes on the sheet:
I2C Addr: 0X18

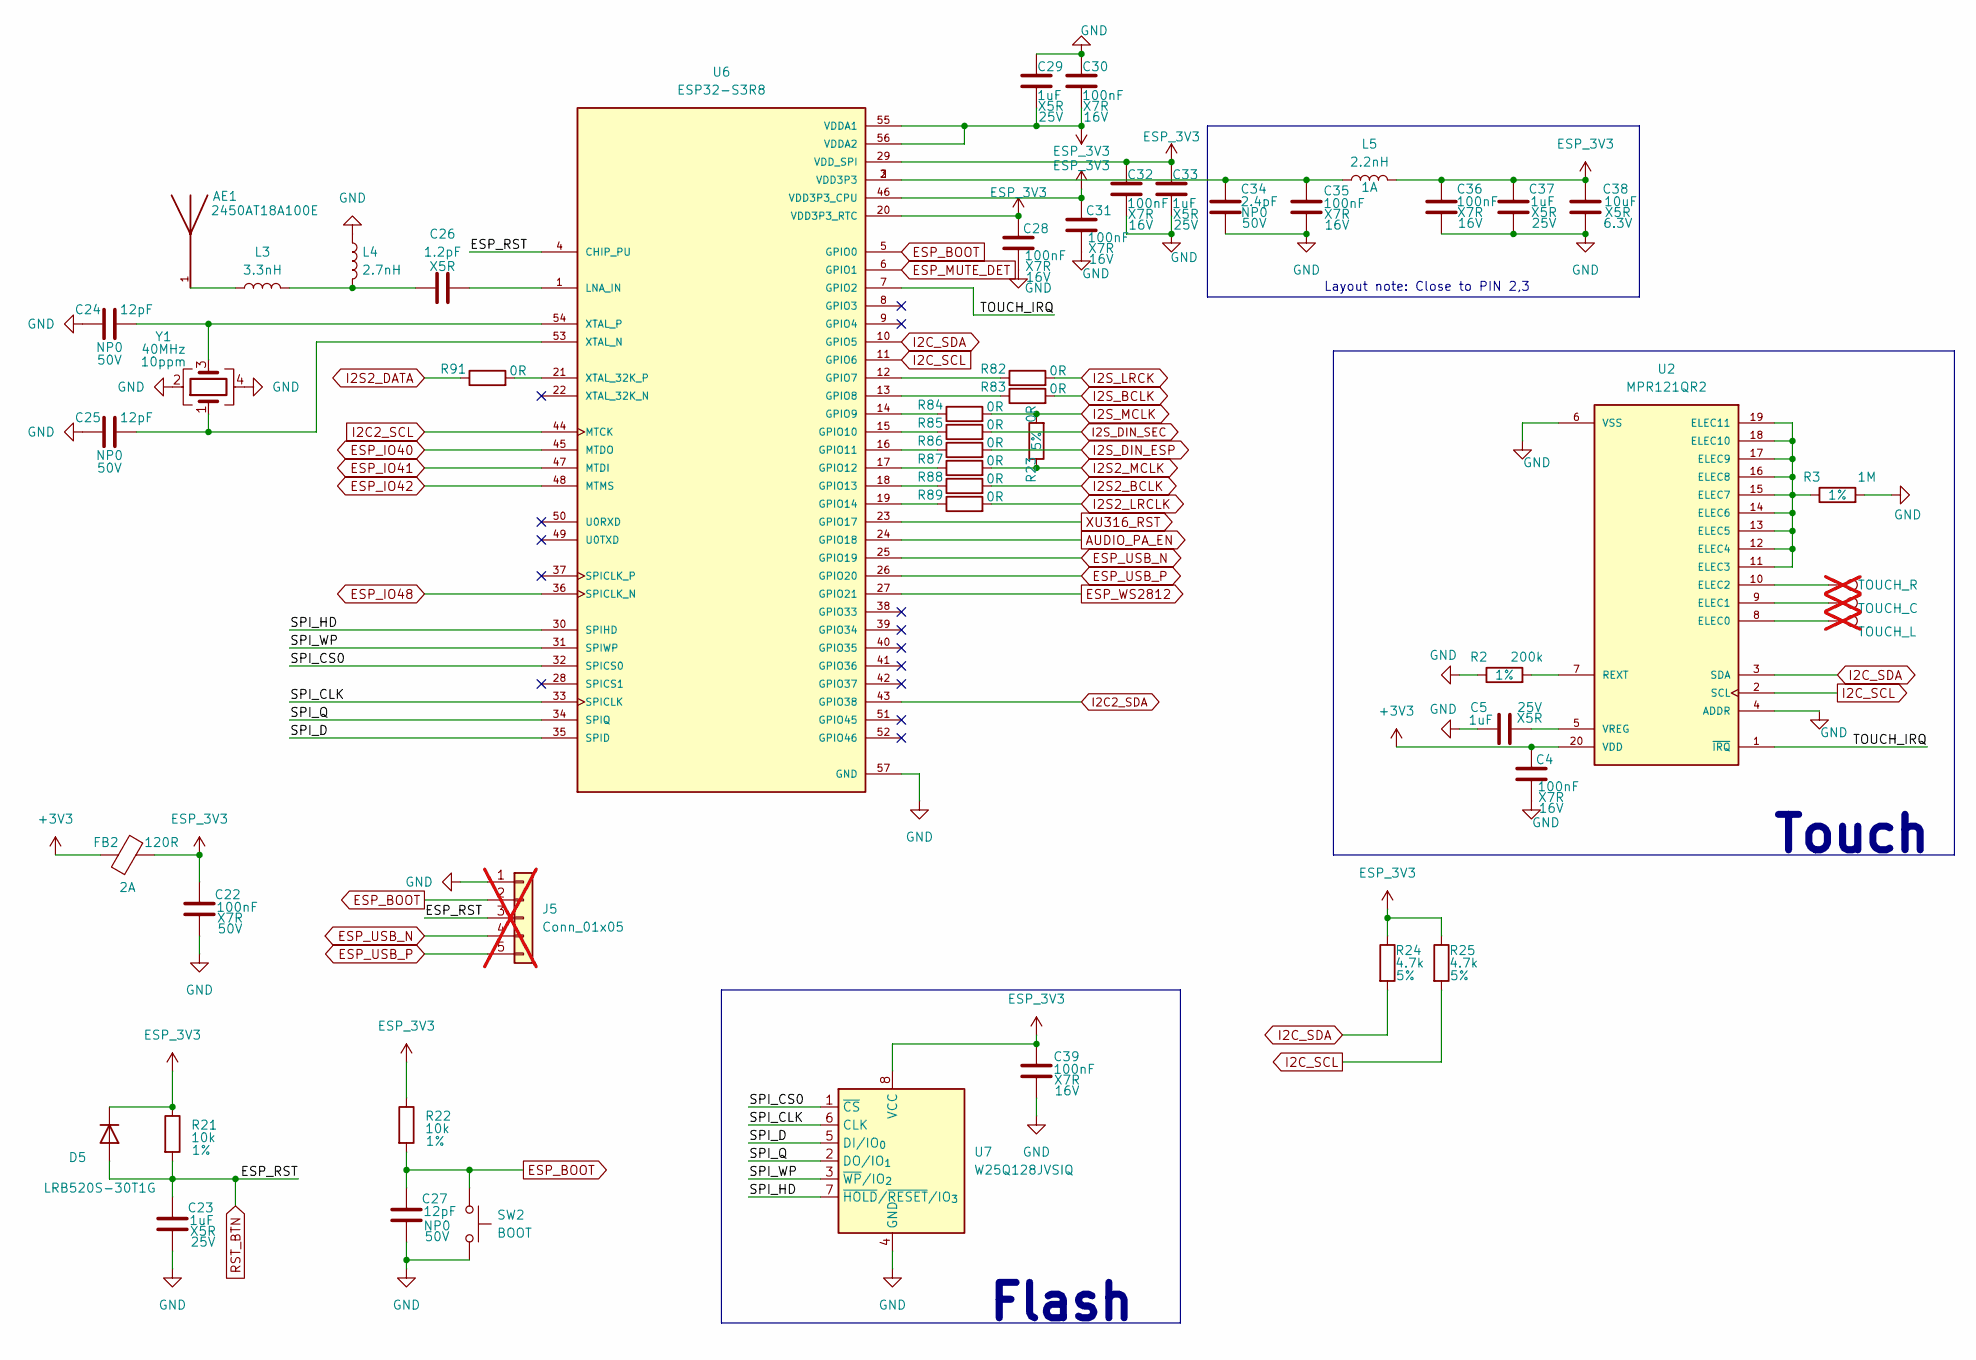
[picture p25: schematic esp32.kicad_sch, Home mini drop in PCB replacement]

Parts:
AE1: 2450AT18A100E; Johanson_2450AT18x100; Manufacturer Part 2450AT18A100E; LCSC Part # C89334
C4, C28, C30, C31, C32, C35, C36, C39: 100nF; C_0402_1005Metric; Voltage 16V; Manufacturer Part CL05B104KO5NNNC; LCSC Part # C1525
C5, C23, C29, C33, C37: 1uF; C_0402_1005Metric; Voltage 25V; Manufacturer Part CL05A105KA5NQNC; LCSC Part # C52923
C22: 100nF; C_0603_1608Metric; Voltage 50V; Manufacturer Part CC0603KRX7R9BB104; LCSC Part # C14663
C24, C25, C27: 12pF; C_0402_1005Metric; Voltage 50V; Manufacturer Part 0402CG120J500NT; LCSC Part # C1547
C26: 1.2pF; C_0402_1005Metric; Voltage 10V; Manufacturer Part CC0402BRNPO9BN1R2; LCSC Part # C327292
C34: 2.4pF; C_0402_1005Metric; Voltage 50V; Manufacturer Part 0402CG2R4C500NT; LCSC Part # C48346
C38: 10uF; C_0402_1005Metric; Voltage 6.3V; Manufacturer Part CL05A106MQ5NUNC; LCSC Part # C15525
D5: LRB520S-30T1G; D_SOD-523; Manufacturer Part LRB520S-30T1G; LCSC Part # C83680
FB2: 120R; BLM18PG121SN1D; Manufacturer Part BLM18PG121SN1D; LCSC Part # C14709
J5: Conn_01x05; PinHeader_1x05_P2.54mm_Vertical; not fitted
L3: 3.3nH; L_0402_1005Metric; Manufacturer Part SDCL1005C3N3STDF; LCSC Part # C16526
L4: 2.7nH; L_0402_1005Metric; Manufacturer Part MHQ1005P2N7BT000; LCSC Part # C434826
L5: 2.2nH; L_0402_1005Metric; Manufacturer Part LQG15HS2N2B02D; LCSC Part # C162540
R2: 200k; R_0402_1005Metric; Tolerance 1%; MPN 0402WGF2003TCE; LCSC Part # C25764
R3: 1M; R_0402_1005Metric; Tolerance 1%; MPN 0402WGJ0105TCE; LCSC Part # C26087
R21, R22: 10k; R_0402_1005Metric; Tolerance 1%; Manufacturer Part 0402WGF1002TCE; LCSC Part # C25744
R23, R82, R83, R84, R85, R86, R87, R88, R89, R91: 0R; R_0402_1005Metric; Tolerance 5%; Manufacturer Part 0402WGF0000TCE; LCSC Part # C17168
R24, R25: 4.7k; R_0402_1005Metric; Tolerance 5%; Manufacturer Part 0402WGF4701TCE; LCSC Part # C25900
SW2: BOOT; SW-SMD_4P-L4.2-W3.2-P2.15-LS4.5; Manufacturer Part PTS810SJS250SMTRLFS; LCSC Part # C221897
TP6: TOUCH_L; TestPoint_Pad_2.5x2.5mm; not fitted
TP7: TOUCH_C; TestPoint_Pad_2.5x2.5mm; not fitted
TP8: TOUCH_R; TestPoint_Pad_2.5x2.5mm; not fitted
U2: MPR121QR2; MPN MPR121QR2; LCSC Part # C91322
U6: ESP32-S3R8; QFN40P700X700X90-57N; Manufacturer Part ESP32-S3R8; LCSC Part # C2913194
U7: W25Q128JVSIQ; SOIC-8_5.3x5.3mm_P1.27mm; Manufacturer Part W25Q128JVSIQ; LCSC Part # C97521
Y1: 40MHz; Crystal_SMD_2016-4Pin_2.0x1.6mm; Tolerance 10ppm; Manufacturer Part TAXM40M4ZCBCDT2T; LCSC Part # C424431

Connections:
+3V3: C4.1, FB2.1, U2.20 (VDD); also elsewhere on the board
/ESP32-S3R8/SPI_CLK: U6.33 (SPICLK), U7.6 (CLK)
/ESP32-S3R8/SPI_CS0: U6.32 (SPICS0), U7.1 (~CS)
/ESP32-S3R8/SPI_D: U6.35 (SPID), U7.5 (DI/IO_{0})
/ESP32-S3R8/SPI_HD: U6.30 (SPIHD), U7.7 (~HOLD/~RESET/IO_{3})
/ESP32-S3R8/SPI_Q: U6.34 (SPIQ), U7.2 (DO/IO_{1})
/ESP32-S3R8/SPI_WP: U6.31 (SPIWP), U7.3 (~WP/IO_{2})
/ESP32-S3R8/TOUCH_IRQ: U2.1 (~IRQ), U6.7 (GPIO2)
AUDIO_PA_EN: U6.24 (GPIO18); also elsewhere on the board
ESP_3V3: C22.1, C28.1, C29.2, C30.2, C31.1, C32.1, C33.1, C36.1, C37.1, C38.1, C39.1, D5.1 (K), FB2.2, L5.2, R21.1, R22.1, R24.1, R25.1, U6.20 (VDD3P3_RTC), U6.29 (VDD_SPI), U6.46 (VDD3P3_CPU), U6.55 (VDDA1), U6.56 (VDDA2), U7.8 (VCC); also elsewhere on the board
ESP_BOOT: C27.1, J5.2, R22.2, SW2.1, U6.5 (GPIO0)
ESP_IO40: U6.45 (MTDO); also elsewhere on the board
ESP_IO41: U6.47 (MTDI); also elsewhere on the board
ESP_IO42: U6.48 (MTMS)
ESP_IO48: U6.36 (SPICLK_N)
ESP_MUTE_DET: U6.6 (GPIO1); also elsewhere on the board
ESP_USB_N: J5.4, U6.25 (GPIO19); also elsewhere on the board
ESP_USB_P: J5.5, U6.26 (GPIO20); also elsewhere on the board
ESP_WS2812: U6.27 (GPIO21); also elsewhere on the board
GND: C4.2, C5.1, C22.2, C23.2, C24.1, C25.1, C27.2, C28.2, C29.1, C30.1, C31.2, C32.2, C33.2, C34.2, C35.2, C36.2, C37.2, C38.2, C39.2, J5.1, L4.1, R2.1, R3.2, SW2.2, U2.4 (ADDR), U2.6 (VSS), U6.57 (GND), U7.4 (GND), Y1.2, Y1.4; also elsewhere on the board
I2C2_SCL: U6.44 (MTCK); also elsewhere on the board
I2C2_SDA: U6.43 (GPIO38); also elsewhere on the board
I2C_SCL: R25.2, U2.2 (SCL), U6.11 (GPIO6); also elsewhere on the board
I2C_SDA: R24.2, U2.3 (SDA), U6.10 (GPIO5); also elsewhere on the board
I2S2_BCLK: R88.2; also elsewhere on the board
I2S2_DATA: R91.1; also elsewhere on the board
I2S2_LRCLK: R89.2; also elsewhere on the board
I2S2_MCLK: R23.1, R87.2; also elsewhere on the board
I2S_BCLK: R83.2; also elsewhere on the board
I2S_DIN_ESP: R86.2; also elsewhere on the board
I2S_DIN_SEC: R85.2; also elsewhere on the board
I2S_LRCK: R82.2; also elsewhere on the board
I2S_MCLK: R23.2, R84.2; also elsewhere on the board
unnamed: AE1.1, L3.1
unnamed: C26.1, L3.2, L4.2
unnamed: C34.1, C35.1, L5.1, U6.2 (VDD3P3), U6.3 (VDD3P3)
unnamed: TP6.1, U2.8 (ELEC0)
unnamed: TP7.1, U2.9 (ELEC1)
unnamed: TP8.1, U2.10 (ELEC2)
unnamed: R3.1, U2.11 (ELEC3), U2.12 (ELEC4), U2.13 (ELEC5), U2.14 (ELEC6), U2.15 (ELEC7), U2.16 (ELEC8), U2.17 (ELEC9), U2.18 (ELEC10), U2.19 (ELEC11)
unnamed: R2.2, U2.7 (REXT)
unnamed: C5.2, U2.5 (VREG)
unnamed: R82.1, U6.12 (GPIO7)
unnamed: R83.1, U6.13 (GPIO8)
unnamed: R84.1, U6.14 (GPIO9)
unnamed: R85.1, U6.15 (GPIO10)
unnamed: R86.1, U6.16 (GPIO11)
unnamed: R87.1, U6.17 (GPIO12)
unnamed: R88.1, U6.18 (GPIO13)
unnamed: R89.1, U6.19 (GPIO14)
unnamed: C26.2, U6.1 (LNA_IN)
unnamed: R91.2, U6.21 (XTAL_32K_P)
unnamed: C25.2, U6.53 (XTAL_N), Y1.1
unnamed: C24.2, U6.54 (XTAL_P), Y1.3
RST_BTN: C23.1, D5.2 (A), J5.3, R21.2, U6.4 (CHIP_PU); also elsewhere on the board
XU316_RST: U6.23 (GPIO17); also elsewhere on the board

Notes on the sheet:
Flash
Touch
Layout note: Close to PIN 2,3

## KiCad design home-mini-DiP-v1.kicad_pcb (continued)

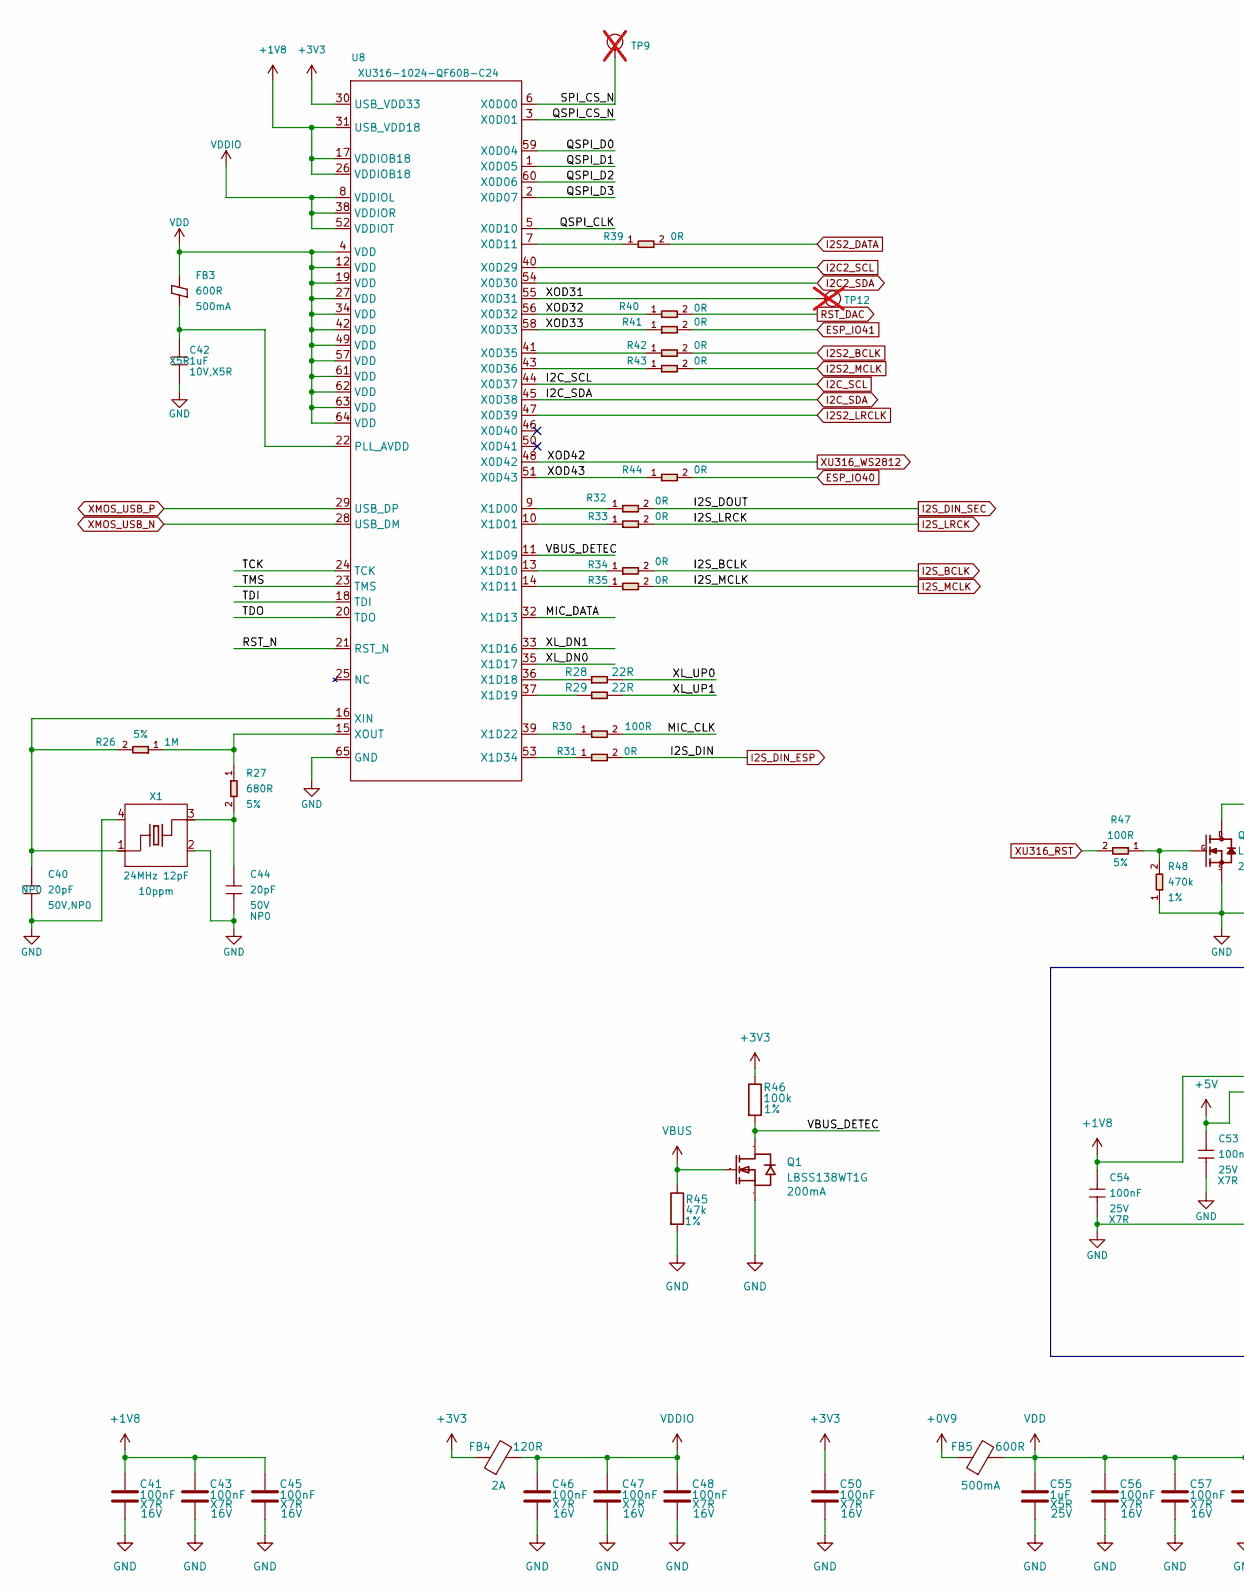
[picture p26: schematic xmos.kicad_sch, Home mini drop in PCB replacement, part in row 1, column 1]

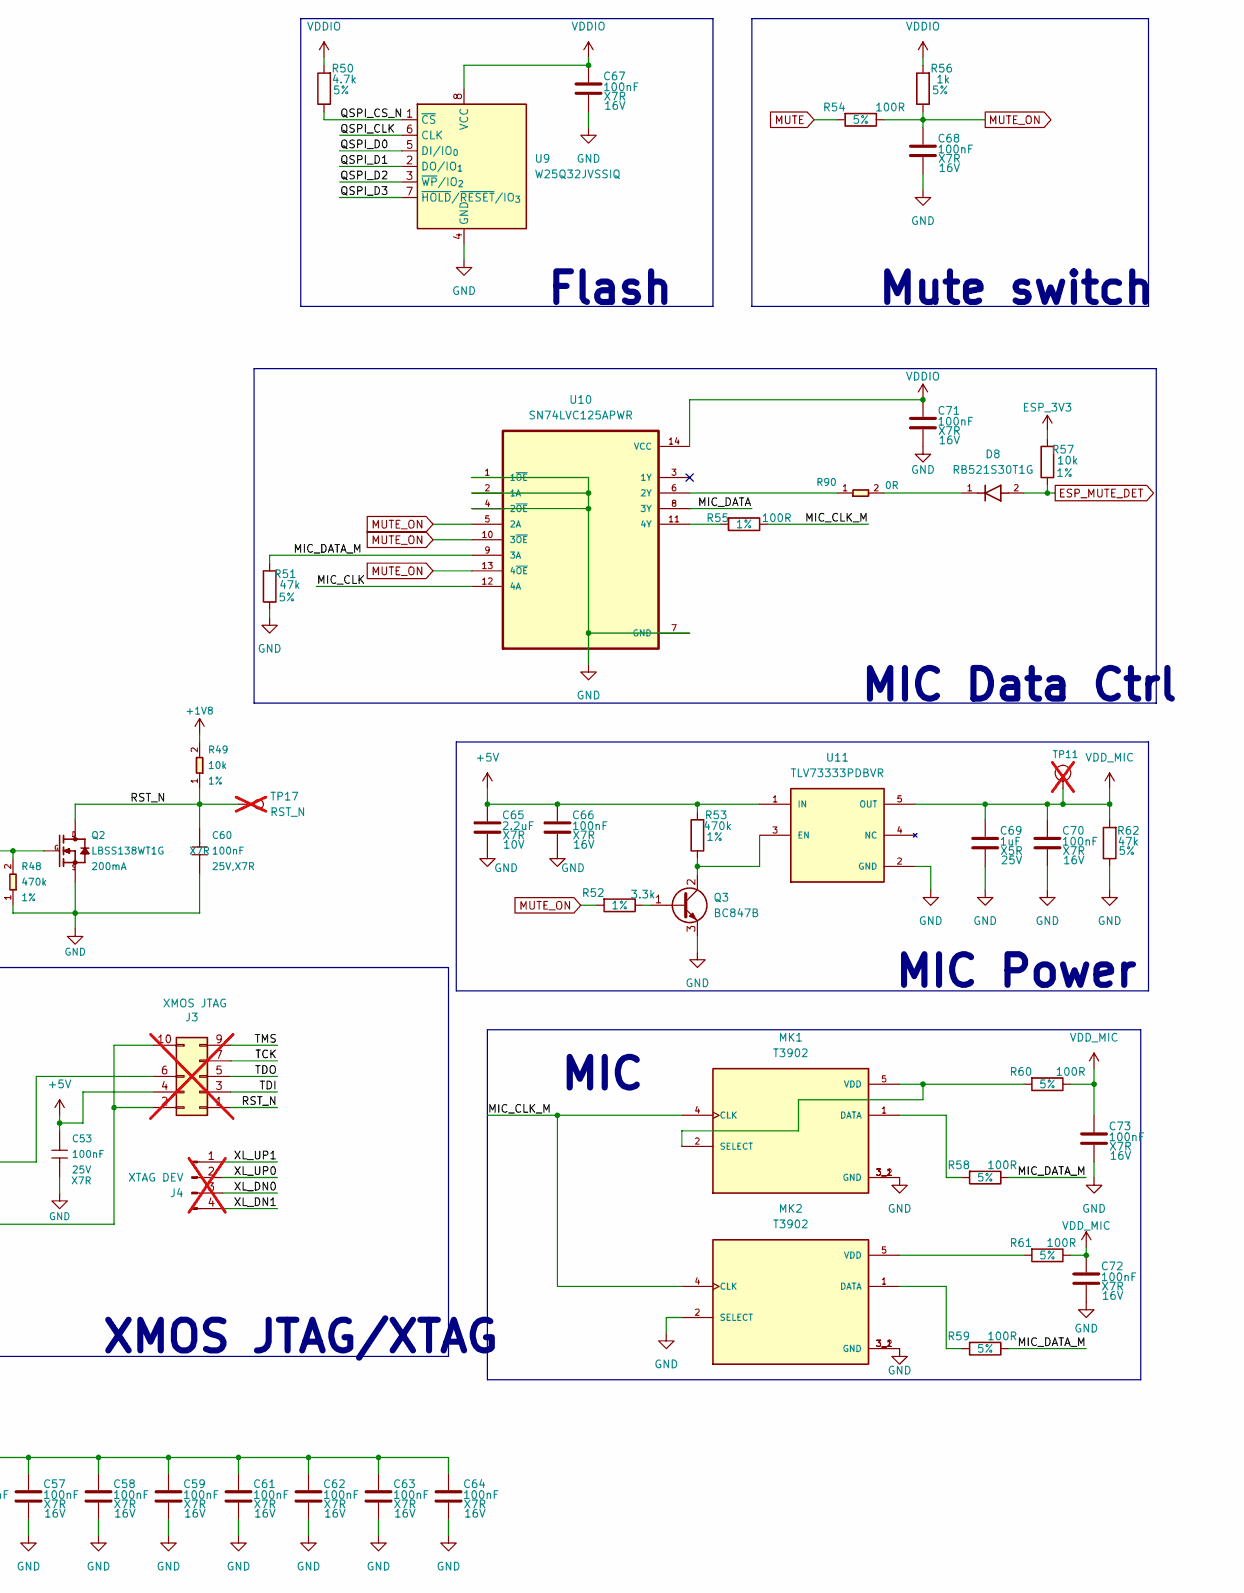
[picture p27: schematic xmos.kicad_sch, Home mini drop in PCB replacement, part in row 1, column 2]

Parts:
C40: 20pF; C_0402_1005Metric; Voltage Rating 50V,NP0; Voltage 50V; MPN 0402CG200J500NT; LCSC Part # C1554
C41, C43, C45, C46, C47, C48, C50, C56, C57, C58, C59, C61, C62, C63, C64, C66, C67, C68, C70, C71, C72, C73: 100nF; C_0402_1005Metric; Voltage 16V; Manufacturer Part CL05B104KO5NNNC; LCSC Part # C1525
C42: 1uF; C_0402_1005Metric; Voltage Rating 10V,X5R; Voltage 25V; MPN CL05A105KA5NQNC; LCSC Part # C52923
C44: 20pF; C_0402_1005Metric; Voltage Rating 50V; Voltage 50V; MPN 0402CG200J500NT; LCSC Part # C1554
C53, C54: 100nF; C_0402_1005Metric; Voltage Rating 25V; Voltage 16V; MPN CL05B104KO5NNNC; LCSC Part # C1525
C55, C69: 1uF; C_0402_1005Metric; Voltage 25V; Manufacturer Part CL05A105KA5NQNC; LCSC Part # C52923
C60: 100nF; C_0402_1005Metric; Voltage Rating 25V,X7R; MPN CL05B104KO5NNNC; LCSC Part # C1525
C65: 2.2uF; C_0603_1608Metric; Voltage 10V; Manufacturer Part GRM188R71A225KE15D; LCSC Part # C86018
D8: RB521S30T1G; DIOM168X70N; Manufacturer Part RB521S30T1G; LCSC Part # C27636108
FB3: 600R; BLM18PG121SN1D; Rating 500mA; MPN BLM18KG601SN1D; LCSC Part # C85833
FB4: 120R; BLM18PG121SN1D; Manufacturer Part BLM18PG121SN1D; LCSC Part # C14709
FB5: 600R; BLM18PG121SN1D; Manufacturer Part BLM18KG601SN1D; LCSC Part # C85833
J3: XMOS JTAG; PinHeader_2x05_P2.54mm_Vertical; not fitted
J4: XTAG DEV; PinHeader_1x04_P2.54mm_Vertical; not fitted
MK1, MK2: T3902; MIC_T3902; Manufacturer Part MMICT390200012; LCSC Part # C3171752
Q1: LBSS138WT1G; SOT-323_SC-70; Manufacturer Part LBSS138WT1G; LCSC Part # C383201
Q2: LBSS138WT1G; SOT-323_SC-70; Rating 200mA; MPN LBSS138WT1G; LCSC Part # C383201
Q3: BC847B; SOT-23; Manufacturer Part BC847B; LCSC Part # C20069135
R26: 1M; R_0402_1005Metric; Power Rating 5%; MPN 0402WGF1004TCE; LCSC Part # C26083
R27: 680R; R_0402_1005Metric; Power Rating 5%; MPN 0402WGF6800TCE; LCSC Part # C25130
R28, R29: 22R; R_0402_1005Metric; Power Rating 5%; MPN 0402WGF220JTCE; LCSC Part # C25092
R30, R47: 100R; R_0402_1005Metric; Power Rating 5%; MPN 0402WGF1000TCE; LCSC Part # C25076
R31, R32, R33, R34, R35, R41, R42, R43, R44: 0R; R_0402_1005Metric; Power Rating 5%; MPN 0402WGF0000TCE; LCSC Part # C17168
R39, R40, R90: 0R; R_0402_1005Metric; Tolerance 5%; MPN 0402WGF0000TCE; LCSC Part # C17168
R45: 47k; R_0402_1005Metric; Tolerance 1%; Manufacturer Part 0402WGF4702TCE; LCSC Part # C25792
R46: 100k; R_0402_1005Metric; Tolerance 1%; Manufacturer Part 0402WGJ0104TCE; LCSC Part # C25530
R48: 470k; R_0402_1005Metric; Power Rating 1%; MPN 0402WGF4703TCE; LCSC Part # C25790
R49: 10k; R_0402_1005Metric; Power Rating 1%; MPN 0402WGF1002TCE; LCSC Part # C25744
R50: 4.7k; R_0402_1005Metric; Tolerance 5%; Manufacturer Part 0402WGF4701TCE; LCSC Part # C25900
R51, R62: 47k; R_0402_1005Metric; Tolerance 5%; Manufacturer Part 0402WGF4702TCE; LCSC Part # C25792
R52: 3.3k; R_0402_1005Metric; Tolerance 1%; Manufacturer Part 0402WGF3301TCE; LCSC Part # C25890
R53: 470k; R_0402_1005Metric; Tolerance 1%; Manufacturer Part 0402WGF4703TCE; LCSC Part # C25790
R54: 100R; R_0402_1005Metric; Tolerance 5%; Power Rating 5%; Manufacturer Part 0402WGF1000TCE; LCSC Part # C25076
R55: 100R; R_0402_1005Metric; Tolerance 1%; Manufacturer Part 0402WGF1000TCE; LCSC Part # C25076
R56: 1k; R_0402_1005Metric; Tolerance 5%; Manufacturer Part 0402WGF1001TCE; LCSC Part # C11702
R57: 10k; R_0402_1005Metric; Tolerance 1%; Manufacturer Part 0402WGF1002TCE; LCSC Part # C25744
R58, R59, R60, R61: 100R; R_0402_1005Metric; Tolerance 5%; Manufacturer Part 0402WGF1000TCE; LCSC Part # C25076
TP9, TP11: TEST-POINT; TestPoint_Pad_D1.0mm; not fitted
TP12: Test Point; TestPoint_Pad_D1.0mm; Part Type Test Point; not fitted
TP17: RST_N; TestPoint_Pad_D1.0mm; not fitted
U8: XU316-1024-QF60B-C24 ; XU316-1024-QF60B-C24; MPN XU316-1024-QF60B-C24; LCSC Part # C6617472
U9: W25Q32JVSSIQ; SOIC-8_5.3x5.3mm_P1.27mm; Manufacturer Part W25Q32JVSSIQ; LCSC Part # C179173
U10: SN74LVC125APWR; SOP65P640X120-14N; Manufacturer Part SN74LVC125APWR; LCSC Part # C7813
U11: TLV73333PDBVR; Manufacturer Part TLV73333PDBVR; LCSC Part # C134139
X1: 24MHz 12pF; X4-SMD-2.0X1.6MM; Rating 10ppm; MPN 7F24000E12UCG; LCSC Part # C252273

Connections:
+0V9: FB5.1; also elsewhere on the board
+1V8: C41.1, C43.1, C45.1, C54.1, J3.6, R49.2, U8.17 (VDDIOB18), U8.26 (VDDIOB18), U8.31 (USB_VDD18); also elsewhere on the board
+3V3: C50.1, FB4.1, R46.1, U8.30 (USB_VDD33); also elsewhere on the board
+5V: C53.1, C65.1, C66.1, J3.4, R53.2, U11.1 (IN); also elsewhere on the board
/XMOS/MIC_CLK: R30.2, U10.12 (4A)
/XMOS/MIC_CLK_M: MK1.4 (CLK), MK2.4 (CLK), R55.1
/XMOS/MIC_DATA: U8.32 (X1D13), U10.8 (3Y)
/XMOS/MIC_DATA_M: R51.2, R58.1, R59.1, U10.9 (3A)
/XMOS/QSPI_CLK: U8.5 (X0D10), U9.6 (CLK)
/XMOS/QSPI_CS_N: R50.1, U8.3 (X0D01), U9.1 (~CS)
/XMOS/QSPI_D0: U8.59 (X0D04), U9.5 (DI/IO_{0})
/XMOS/QSPI_D1: U8.1 (X0D05), U9.2 (DO/IO_{1})
/XMOS/QSPI_D2: U8.60 (X0D06), U9.3 (~WP/IO_{2})
/XMOS/QSPI_D3: U8.2 (X0D07), U9.7 (~HOLD/~RESET/IO_{3})
/XMOS/RST_N: C60.1, J3.1, Q2.3 (D), R49.1, TP17.1, U8.21 (RST_N)
/XMOS/SPI_CS_N: TP9.1 (T), U8.6 (X0D00)
/XMOS/TCK: J3.7, U8.24 (TCK)
/XMOS/TDI: J3.3, U8.18 (TDI)
/XMOS/TDO: J3.5, U8.20 (TDO)
/XMOS/TMS: J3.9, U8.23 (TMS)
/XMOS/VBUS_DETEC: Q1.3 (D), R46.2, U8.11 (X1D09)
/XMOS/XL_DN0: J4.3, U8.35 (X1D17)
/XMOS/XL_DN1: J4.4, U8.33 (X1D16)
/XMOS/XL_UP0: J4.2, R28.2
/XMOS/XL_UP1: J4.1, R29.2
/XMOS/XOD31: TP12.1 (T), U8.55 (X0D31)
/XMOS/XOD32: R40.1, U8.56 (X0D32)
/XMOS/XOD33: R41.1, U8.58 (X0D33)
/XMOS/XOD43: R44.1, U8.51 (X0D43)
ESP_3V3: R57.2; also elsewhere on the board
ESP_IO40: R44.2; also elsewhere on the board
ESP_IO41: R41.2; also elsewhere on the board
ESP_MUTE_DET: D8.2, R57.1; also elsewhere on the board
GND: C40.2, C41.2, C42.2, C43.2, C44.2, C45.2, C46.2, C47.2, C48.2, C50.2, C53.2, C54.2, C55.2, C56.2, C57.2, C58.2, C59.2, C60.2, C61.2, C62.2, C63.2, C64.2, C65.2, C66.2, C67.2, C68.2, C69.2, C70.2, C71.2, C72.2, C73.2, J3.2, J3.10, MK1.3_1 (GND), MK1.3_2 (GND), MK2.2 (SELECT), MK2.3_1 (GND), MK2.3_2 (GND), Q1.2 (S), Q2.2 (S), Q3.3 (E), R45.2, R48.1, R51.1, R62.1, U8.65 (GND), U9.4 (GND), U10.1 (1~OE), U10.2 (1A), U10.4 (2~OE), U10.7 (GND), U11.2 (GND), X1.2, X1.4; also elsewhere on the board
I2C2_SCL: U8.40 (X0D29); also elsewhere on the board
I2C2_SDA: U8.54 (X0D30); also elsewhere on the board
I2C_SCL: U8.44 (X0D37); also elsewhere on the board
I2C_SDA: U8.45 (X0D38); also elsewhere on the board
I2S2_BCLK: R42.2; also elsewhere on the board
I2S2_DATA: R39.2; also elsewhere on the board
I2S2_LRCLK: U8.47 (X0D39); also elsewhere on the board
I2S2_MCLK: R43.2; also elsewhere on the board
I2S_BCLK: R34.2; also elsewhere on the board
I2S_DIN_ESP: R31.2; also elsewhere on the board
I2S_DIN_SEC: R32.2; also elsewhere on the board
I2S_LRCK: R33.2; also elsewhere on the board
I2S_MCLK: R35.2; also elsewhere on the board
MUTE: R54.2; also elsewhere on the board
MUTE_ON: C68.1, R52.2, R54.1, R56.1, U10.5 (2A), U10.10 (3~OE), U10.13 (4~OE)
unnamed: C44.1, R27.2, X1.3
unnamed: D8.1, R90.2
unnamed: MK1.1 (DATA), R58.2
unnamed: MK1.2 (SELECT), MK1.5 (VDD), R60.2
unnamed: MK2.1 (DATA), R59.2
unnamed: MK2.5 (VDD), R61.2
unnamed: Q2.1 (G), R47.1, R48.2
unnamed: Q3.1 (B), R52.1
unnamed: Q3.2 (C), R53.1, U11.3 (EN)
unnamed: C42.1, FB3.1, U8.22 (PLL_AVDD)
unnamed: R39.1, U8.7 (X0D11)
unnamed: R42.1, U8.41 (X0D35)
unnamed: R43.1, U8.43 (X0D36)
unnamed: R32.1, U8.9 (X1D00)
unnamed: R33.1, U8.10 (X1D01)
unnamed: R34.1, U8.13 (X1D10)
unnamed: R35.1, U8.14 (X1D11)
unnamed: R28.1, U8.36 (X1D18)
unnamed: R29.1, U8.37 (X1D19)
unnamed: R30.1, U8.39 (X1D22)
unnamed: R31.1, U8.53 (X1D34)
unnamed: C40.1, R26.2, U8.16 (XIN), X1.1
unnamed: R26.1, R27.1, U8.15 (XOUT)
unnamed: R90.1, U10.6 (2Y)
unnamed: R55.2, U10.11 (4Y)
RST_DAC: R40.2; also elsewhere on the board
VBUS: Q1.1 (G), R45.1; also elsewhere on the board
VDD: C55.1, C56.1, C57.1, C58.1, C59.1, C61.1, C62.1, C63.1, C64.1, FB3.2, FB5.2, U8.4 (VDD), U8.12 (VDD), U8.19 (VDD), U8.27 (VDD), U8.34 (VDD), U8.42 (VDD), U8.49 (VDD), U8.57 (VDD), U8.61 (VDD), U8.62 (VDD), U8.63 (VDD), U8.64 (VDD)
VDDIO: C46.1, C47.1, C48.1, C67.1, C71.1, FB4.2, R50.2, R56.2, U8.8 (VDDIOL), U8.38 (VDDIOR), U8.52 (VDDIOT), U9.8 (VCC), U10.14 (VCC)
VDD_MIC: C69.1, C70.1, C72.1, C73.1, R60.1, R61.1, R62.2, TP11.1 (T), U11.5 (OUT)
XMOS_USB_N: U8.28 (USB_DM)
XMOS_USB_P: U8.29 (USB_DP)
XU316_RST: R47.2; also elsewhere on the board
XU316_WS2812: U8.48 (X0D42)

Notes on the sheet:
Flash
MIC
Mute switch
MIC Power
MIC Data Ctrl
XMOS JTAG/XTAG

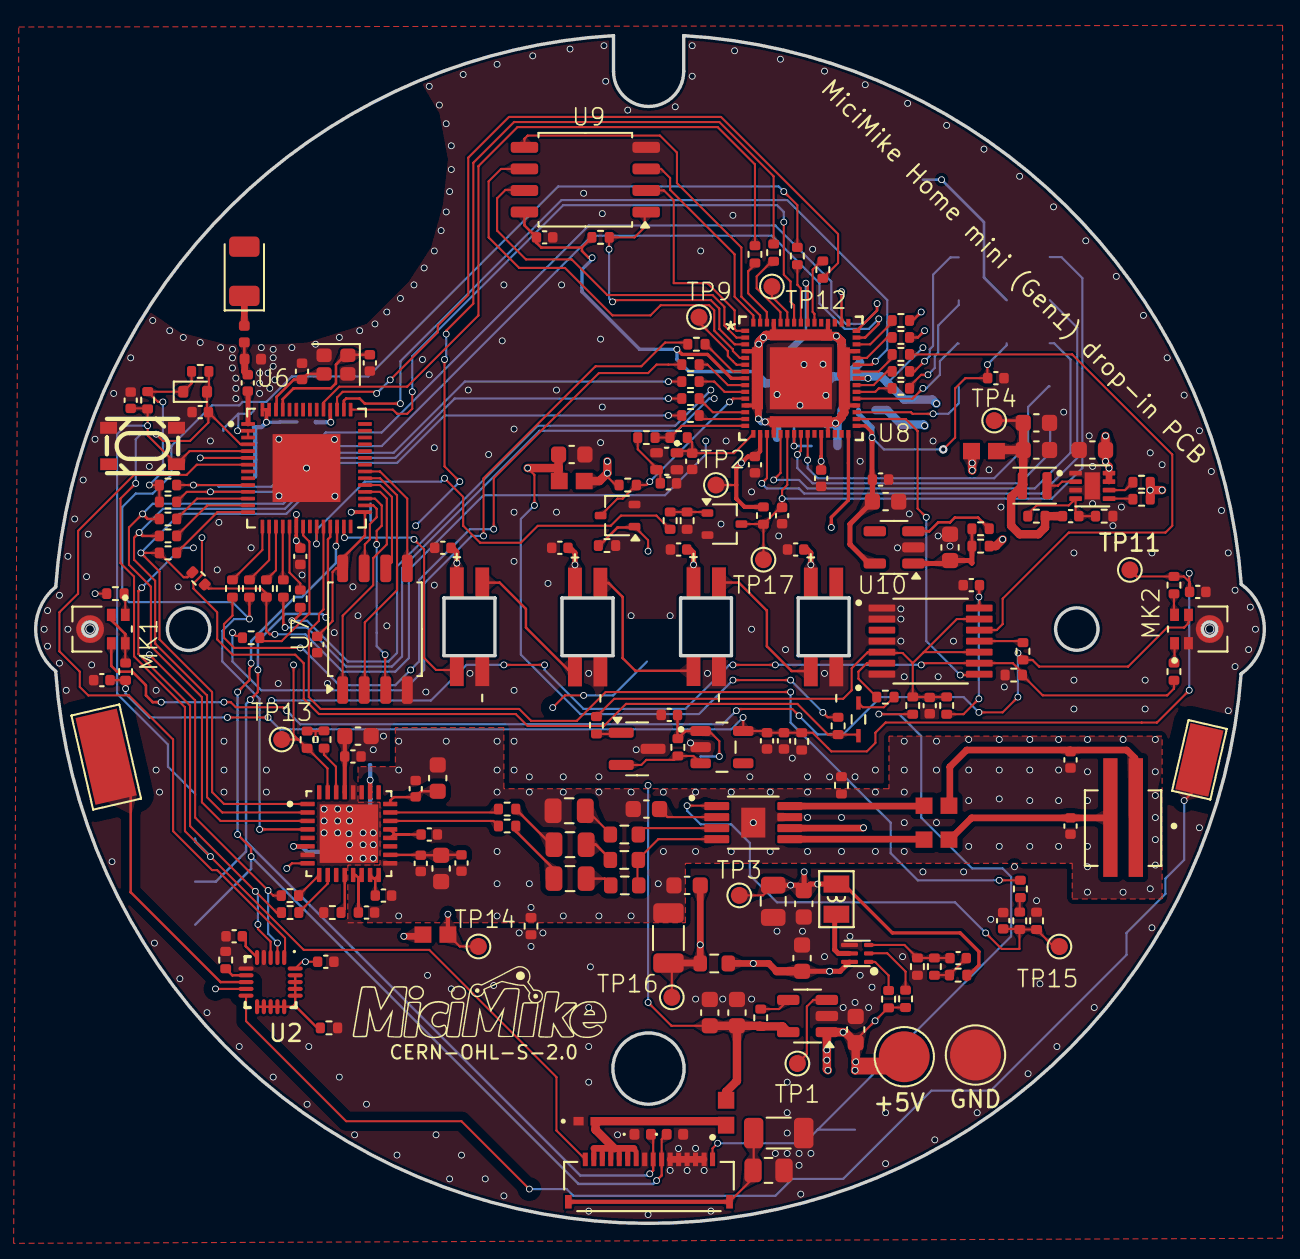
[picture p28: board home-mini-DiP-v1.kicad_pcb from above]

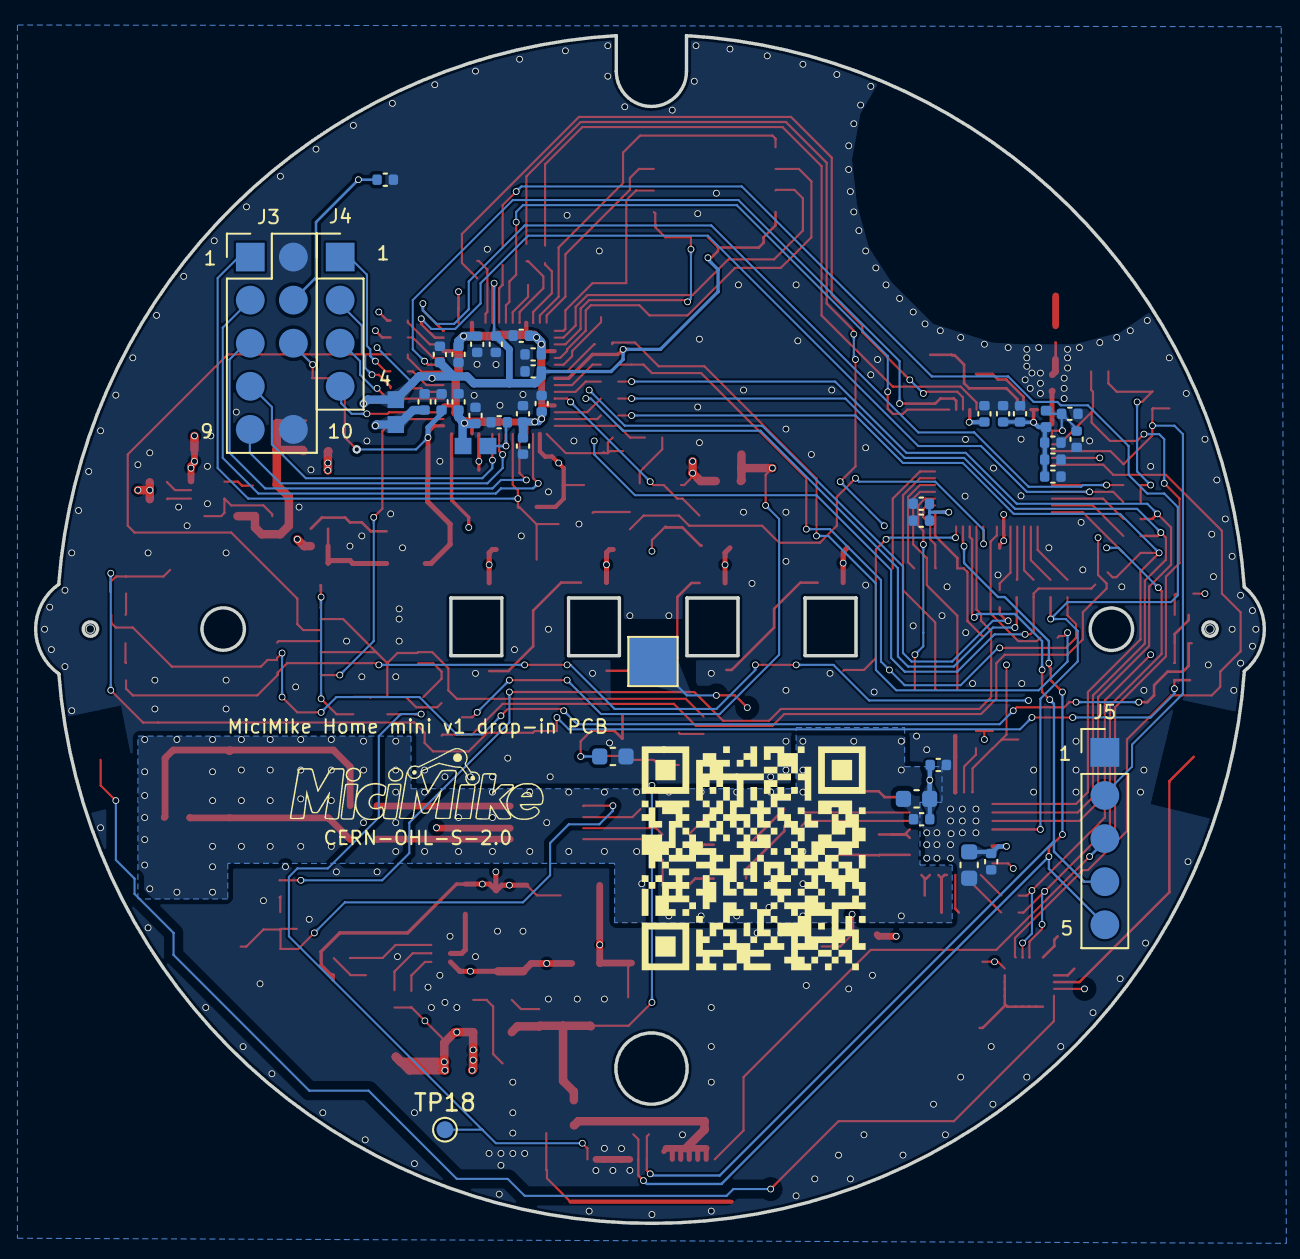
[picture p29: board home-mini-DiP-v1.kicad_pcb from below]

Board: 4 copper layers, 72.4 x 70.0 mm, 241 parts (40 on the bottom side), 161 nets.

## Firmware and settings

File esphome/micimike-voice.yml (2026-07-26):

substitutions:
  # Phases of the Voice Assistant
  # The voice assistant is ready to be triggered by a wake word
  voice_assist_idle_phase_id: '1'
  # The voice assistant is waiting for a voice command (after being triggered by the wake word)
  voice_assist_waiting_for_command_phase_id: '2'
  # The voice assistant is listening for a voice command
  voice_assist_listening_for_command_phase_id: '3'
  # The voice assistant is currently processing the command
  voice_assist_thinking_phase_id: '4'
  # The voice assistant is replying to the command
  voice_assist_replying_phase_id: '5'
  # The voice assistant is not ready
  voice_assist_not_ready_phase_id: '10'
  # The voice assistant encountered an error
  voice_assist_error_phase_id: '11'
  # Change this to true in case you ahve a hidden SSID at home.
  hidden_ssid: "false"
  # Substitutions for audio files
  mute_switch_on_sound_file: https://github.com/esphome/home-assistant-voice-pe/raw/dev/sounds/mute_switch_on.flac
  mute_switch_off_sound_file: https://github.com/esphome/home-assistant-voice-pe/raw/dev/sounds/mute_switch_off.flac
  timer_finished_sound_file: https://github.com/esphome/home-assistant-voice-pe/raw/dev/sounds/timer_finished.flac
  wake_word_triggered_sound_file: https://github.com/esphome/home-assistant-voice-pe/raw/dev/sounds/wake_word_triggered.flac
  volume_tick_sound_file: https://raw.githubusercontent.com/iMike78/home-mini-v1-drop-in-pcb/main/sounds/volume.flac
  center_button_press_sound_file: https://github.com/esphome/home-assistant-voice-pe/raw/dev/sounds/center_button_press.flac
  center_button_double_press_sound_file: https://github.com/esphome/home-assistant-voice-pe/raw/dev/sounds/center_button_double_press.flac
  center_button_triple_press_sound_file: https://github.com/esphome/home-assistant-voice-pe/raw/dev/sounds/center_button_triple_press.flac
  center_button_long_press_sound_file: https://github.com/esphome/home-assistant-voice-pe/raw/dev/sounds/center_button_long_press.flac
  factory_reset_initiated_sound_file: https://github.com/esphome/home-assistant-voice-pe/raw/dev/sounds/factory_reset_initiated.mp3
  factory_reset_cancelled_sound_file: https://github.com/esphome/home-assistant-voice-pe/raw/dev/sounds/factory_reset_cancelled.mp3
  factory_reset_confirmed_sound_file: https://github.com/esphome/home-assistant-voice-pe/raw/dev/sounds/factory_reset_confirmed.mp3
  easter_egg_tick_sound_file: https://github.com/esphome/home-assistant-voice-pe/raw/dev/sounds/easter_egg_tick.mp3
  easter_egg_tada_sound_file: https://github.com/esphome/home-assistant-voice-pe/raw/dev/sounds/easter_egg_tada.mp3
  error_cloud_expired_sound_file: https://github.com/esphome/home-assistant-voice-pe/raw/dev/sounds/error_cloud_expired.mp3
  name: micimike
  friendly_name: MiciMike voice assistant

esphome:
  name: "${name}"
  friendly_name: "${friendly_name}"
  project: 
    name: imike78.micimike
    version: v0.9.8.2
  name_add_mac_suffix: true
  min_version: "2026.7.0"
  on_boot:
    - priority: 375
      then:
        # Run the script to refresh the LED status
        - script.execute: control_leds
        - delay: 1s
        - switch.turn_on: internal_speaker_amp
        # If after 10 minutes, the device is still initializing (It did not yet connect to Home Assistant), turn off the init_in_progress variable and run the script to refresh the LED status
        - delay: 10min
        - if:
            condition:
              lambda: return id(init_in_progress);
            then:
              - lambda: id(init_in_progress) = false;
              - script.execute: control_leds
    - priority: -100
      then:
        - script.execute: configure_mpr121

dashboard_import:
  package_import_url: github://iMike78/home-mini-v1-drop-in-pcb/esphome/micimike-voice.yml@main
  import_full_config: true

esp32:
  board: esp32-s3-devkitc-1
  cpu_frequency: 240MHz
  variant: esp32s3
  flash_size: 16MB
  framework:
    type: esp-idf
    version: recommended
    sdkconfig_options:
      CONFIG_ESP32S3_DATA_CACHE_64KB: "y"
      CONFIG_ESP32S3_DATA_CACHE_LINE_64B: "y"
      CONFIG_ESP32S3_INSTRUCTION_CACHE_32KB: "y"

      # Moves instructions and read only data from flash into PSRAM on boot.
      # Both enabled allows instructions to execute while a flash operation is in progress without needing to be placed in IRAM.
      # Considerably speeds up mWW at the cost of using more PSRAM.
      CONFIG_SPIRAM_RODATA: "y"
      CONFIG_SPIRAM_FETCH_INSTRUCTIONS: "y"

      CONFIG_BT_ALLOCATION_FROM_SPIRAM_FIRST: "y"
      CONFIG_BT_BLE_DYNAMIC_ENV_MEMORY: "y"

      CONFIG_MBEDTLS_EXTERNAL_MEM_ALLOC: "y"
      CONFIG_MBEDTLS_SSL_PROTO_TLS1_3: "y"  # TLS1.3 support isn't enabled by default in IDF 5.1.5
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

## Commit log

2025-08-05 work in progress
    [1775443-2.stp]
2025-08-08 getting ready for production
    [esp32.kicad_sch, power_handling.kicad_sch]
2025-08-10 update for production
    [audio.kicad_sch, esp32.kicad_sch, leds.kicad_sch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]
2025-09-16 error corrections
    [home-mini-v1-drop-in-pcb.kicad_pcb, power_handling.kicad_sch]
2025-10-02 prepare for the 1st test batch
    [audio.kicad_sch, esp32.kicad_sch, home-mini-v1-drop-in-pcb.kicad_pcb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]
2025-10-25 routing done
    [esp32.kicad_sch, home-mini-v1-drop-in-pcb.kicad_pcb, power_handling.kicad_sch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]
2025-11-04 ready for the 1st test batch
    [audio.kicad_sch, esp32.kicad_sch, home-mini-v1-drop-in-pcb.kicad_pcb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]
2025-11-29 mods after 1st batch testing
    [audio.kicad_sch, esp32.kicad_sch, home-mini-v1-drop-in-pcb.kicad_pcb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]
2025-12-01 Add a picture of first the batch prototype to README
    Add a picture of first the batch prototype to README
2025-12-01 Add picture of first the batch prototype for README
    Add picture of first the batch prototype for README
2025-12-03 final mods before production
    [home-mini-v1-drop-in-pcb.kicad_pcb, power_handling.kicad_sch, xmos.kicad_sch]
2025-12-07 Update README with PCB ordering and discussion links
    Added ordering information and a discussion link for the PCB.
2025-12-07 Update README with extra component requirement
    Added information about an extra component required for PCB installation.
2025-12-08 Update FPC cable description in README
2025-12-08 Revise PCB order procedure reference in README
    Updated the link for PCB order procedure information.
2026-01-02 Update README with PCB details and image
    Added an image to the README and clarified PCB details.
2026-02-15 esphome code bugfix
    volume_down loop fixed
    [micimike-voice.yml]
2026-02-28 Silkscreen clearout
    [home-mini-DiP-v1.kicad_pcb]
2026-02-28 version number bug update
    [micimike-voice.yml]
2026-04-07 pcb antenna finetuning
    [home-mini-DiP-v1.kicad_pcb, power_handling.kicad_sch]
2026-05-02 repository cleanup
    [home-mini-v1-drop-in-pcb.csv, home-mini-v1-drop-in-pcb.kicad_pcb, home-mini-v1-drop-in-pcb.kicad_sch]
2026-05-10 v2 hardware revision
    MPR121 touch controller added to replace esp32-s3 integrated touch pins
    [audio.kicad_sch, esp32.kicad_sch, home-mini-DiP-v1.kicad_pcb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]
2026-05-10 Update README for v0.9.5 changes and test points
    Updated README to include v0.9.5 changes regarding the touch controller migration to MPR121 and added new solderable test points.
2026-06-12 production update + esphome fw update + latest render pics
    [home-mini-DiP-v1.kicad_pcb]
2026-07-25 Pin ESPHome build version
2026-07-26 Fix factory dashboard import to use full voice config
    Point dashboard_import at micimike-voice.yml with import_full_config
    enabled so new device adoptions in Home Assistant get the complete
    voice firmware config instead of a short wrapper pointing back to
    micimike-factory.yml. Devices adopted before this fix keep their old
    wrapper config and must be re-adopted or manually repaired.
2026-07-26 Release v0.9.8.2 firmware
    - Fix factory dashboard import to pull the full voice config on Home
    Assistant takeover instead of a wrapper pointing back to factory.yml
    - Distinguish microphone mute vs speaker mute on the timer LED ring
    effects using separate LED pairs (1st/3rd for mic, 2nd/4th for speaker)
    - Update pinned GitHub Actions to Node.js 24-compatible versions
    (checkout@v7, setup-python@v7, action-gh-release@v3)
    - Bump firmware and manifest versions to v0.9.8.2
    [micimike-voice.yml]
2026-07-30 layout optimization for touch pads
    [home-mini-DiP-v1.kicad_pcb]
